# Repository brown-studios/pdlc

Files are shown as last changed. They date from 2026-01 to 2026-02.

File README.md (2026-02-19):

# PDLC driver

Drives [polymer dispersed liquid crystal (PDLC) film](https://en.wikipedia.org/wiki/Smart_glass#Polymer-dispersed_liquid-crystal_devices) from a 12 V DC nominal power supply.

PDLC film is opaque when turned off and becomes clear when turned on.  For example, you can apply it to a window to replace a privacy curtain or to create a diffuse surface for a projection screen on demand.

## Features

Here are some of the features of this PDLC driver board:

- Runs on a 12 V DC battery or power supply at a maximum of 16 V DC
- Drives approximately 4 square meters of PDLC film depending on its electrical characteristics with 15 W of power at 60 V AC peak-to-peak nominal
- Shuts off automatically to protect the battery when the supply voltage falls below 10.6 V DC and resumes operation at 11.5 V
- Includes several forms of circuit protection for the supply and the film
- Detach the terminal blocks from the device for easier wiring
- Optional external I/O functions
  - Connect the mode input to an external momentary push button or a normally open switch to control the state of the film from a convenient location
  - Connect the output enable control signal to a switch to control whether the PDLC film is operable (e.g. can be wired to a door sensor to prevent activation of the film when the door is opened)
  - Connect the auxiliary load output to control another device in tandem with the PDLC film, supports low-side switching of a 200 mA load at up to 20 V maximum (e.g. can be wired to an external indicator)
  - Connect an external I2C controller to control the driver programmatically
  - Connect your own accessories to the expansion port

Please refer to the [design and errata](./hardware/v2/design-and-errata.md) for technical details and schematics.

## Usage

If you have not yet [installed](#installation) and [setup](#setup) the device, do that first then proceed with usage.

How you use the PDLC driver depends on how you have configured it and integrated it with other systems.

By default, the PDLC film toggles on and off when you press the `MODE` button on the device.  When the film is on, it will turn clear, and when it is off, it will become diffuse and provide privacy.  The transition usually happens in less than a second but the film may take longer to change depending on your configuration settings or when the window is very cold.

You can connect an external push button or switch to change the state of the film from a more convenient location. If you have one, use that actuator instead of the `MODE` button.

As a safety feature, the film will not turn on unless the output enable control signal is active, so you may also need to perform another action to enable the film (such as closing the door if you have connected the output enable to a door switch).

You can connect an auxiliary load to the PDLC driver and configure it such that it turns on or off based on the state of the PDLC film automatically. So turning on or off the PDLC film can have additional effects depending on how you have wired things up.

Also, you can programmatically control the PDLC driver using I2C and adjust many internal settings and use advanced functionality such as dimming.  You'll need to write code for this or use an integration that someone else has made.

The `POWER` indicator illuminates for 10 seconds after you supply power to the device then turns off.

The `STATUS` indicator color indicates the status of the PDLC driver during normal operation.  The indicator may blink a certain number of times, pause, then repeat to encode information about a problem.  This table explains the significance of the patterns.

| Status color | Pattern | Meaning |
| --- | --- | --- |
| GREEN | steady | The PDLC driver is providing power to the PDLC film. |
| YELLOW | steady | The PDLC driver is turning on and verifying its operation. |
| AMBER | 1 blink | The PDLC driver was commanded to turn the film on but the output enable control signal is inactive so the driver is not providing power to the PDLC film. |
| RED | 1 blinks | HV_TIMEOUT: Boost converter did not report power good within the expected time after being enabled. |
| RED | 2 blinks | HV_FAULT: Boost converter reported power good then subsequently reported not power good. |
| RED | 3 blinks | OUTPUT_TIMEOUT: Buck converter did not report power good within the expected time after being enabled. |
| RED | 4 blinks | OUTPUT_FAULT: Buck converter reported power good then subsequently reported not power good. |
| RED | 5 blinks | DRIVER: An error occurred in the driver. |

Refer to the [setup](#setup) guide for information about how this indicator is used while configuring settings.

## Troubleshooting

When the PDLC film doesn't turn on when you think it should...

- Try turning the film off then on again and look at the `STATUS` indicator for clues.  Perhaps the output is not enabled.
- Disconnect and reconnect power to the device.  The `POWER` indicator should illuminate briefly once power is connected.
- Ensure that your power supply or battery is supplying at least 11.5 V to the device.
- Check that the settings are compatible with your installation.
- If under programmatic control, disconnect the external I2C controller, factory reset the settings, and try again using the built-in buttons to confirm basic operation.
- Check all wiring connections, fuses, and external control inputs.

When the PDLC film doesn't turn off when you think it should...

- Check that the settings are compatible with your installation.
- Check all wiring connections, fuses, and external control inputs.

## Setup

If you have not yet [installed](#installation) the device, do that first then proceed with setup.

Start by locating the `MODE` button, `SET` button, and `STATUS` indicator on the PDLC driver [as shown during installation](#installation).  Here's how to navigate the setting menus.

1. If you have connected an external switch to the `CONTROL CTRL_MODE_IN` terminal, then turn the switch off before changing settings to prevent interference with the `MODE` push button of the PDLC driver.
2. Press the `SET` button to turn off the PDLC film and enter the first setting menu.
3. Look at the `STATUS` indicator.
  - The color of the status indicator tells you which setting menu is active.
  - The indicator will blink a certain number of times, pause, then repeat.  The number of blinks tells you which option of the setting menu is selected.
4. Press the `MODE` button to advance to the next option.  The indicator will begin blinking a different number of times corresponding to the newly selected option.
5. Press the `SET` button to advance to the next setting menu and the color of the `STATUS` indicator will change.  Repeat from step 3 to continue changing settings.
6. Once you have configured the last option, the `STATUS` indicator will turn off and return to normal function.  Similarly, if you wait 30 seconds without interacting with the setting menu the device will exit the setting menu automatically.

> ![IMPORTANT]
> To reset the device to factory default settings, press and hold the `SET` button for 10 seconds until the indicator cycles through a rainbow pattern to confirm.

| Menu color | Option blinks  | Behavior |
| --- | --- | --- |
| BLUE | 1 (default) | The PDLC film toggles on and off each time `MODE` is pressed. Use this option when you connect a momentary push button to the `CONTROL CTRL_MODE_IN` terminal. |
| BLUE | 2 | The PDLC film turns on while `MODE` is pressed and turns off while `MODE` is released. Use this option when you connect a normally open switch to the `CONTROL CTRL_MODE_IN` terminal. |
| BLUE | 3 | The PDLC film state is always on whenever the output enable control signal is active. Use this option when you are controlling the PDLC driver programmatically and do not want the `MODE` button to interfere. |
| BLUE | 4 | The PDLC film state is always off. Use this option when you are controlling the PDLC driver programmatically and do not want the `MODE` button to interfere. |
| MAGENTA | 1 (default) | The PDLC film transitions from opaque to clear as quickly as possible. |
| MAGENTA | 2 | The PDLC film transitions from opaque to clear gradually over a duration of about 0.5 seconds. |
| MAGENTA | 3 | The PDLC film transitions from opaque to clear gradually over a duration of about 1 second. |
| MAGENTA | 4 | The PDLC film transitions from opaque to clear gradually over a duration of about 2 seconds. |
| CYAN | 1 (default) | The auxiliary load output turns on when the PDLC film is on and turns off otherwise (same state). |
| CYAN | 2 | The auxiliary load output turns off when the PDLC film is on and turns on otherwise (opposite state). |
| CYAN | 3 | The auxiliary load output is always on. |
| CYAN | 4 | The auxiliary load output is always off. |

## Installation

To begin installing and using your PDLC driver, locate these parts of your device:

| Part | Function |
| --- | --- |
| `POWER` terminal block | Connect the power supply and the PDLC film as described in the [wiring guide](#wiring). |
| `CONTROL` terminal block | Connect the control inputs and outputs as described in the [wiring guide](#wiring). |
| `POWER` indicator | Indicates that the device has power.  Turns off automatically after a few seconds of inactivity. |
| `STATUS` indicator | Indicates the status of the device and provides visual feedback while you configure settings. |
| `MODE` button | By default, toggles the PDLC panel on/off.  Can be configured to behave in other ways. |
| `SET` button | Configures device settings. |
| `EN` solder jumper | Solder closed to force the output enable control signal to be always active. |
| `EXT I2C` connector | Allows an external device to control the PDLC driver programmatically using a [QWIIC-compatible](https://www.sparkfun.com/qwiic) I2C interface with galvanic isolation. Additional I2C devices can also be connected in a daisy-chain. |
| `EXPANSION` header | Connect your own accessories to this port to take advantage of otherwise unused microcontroller pins. |

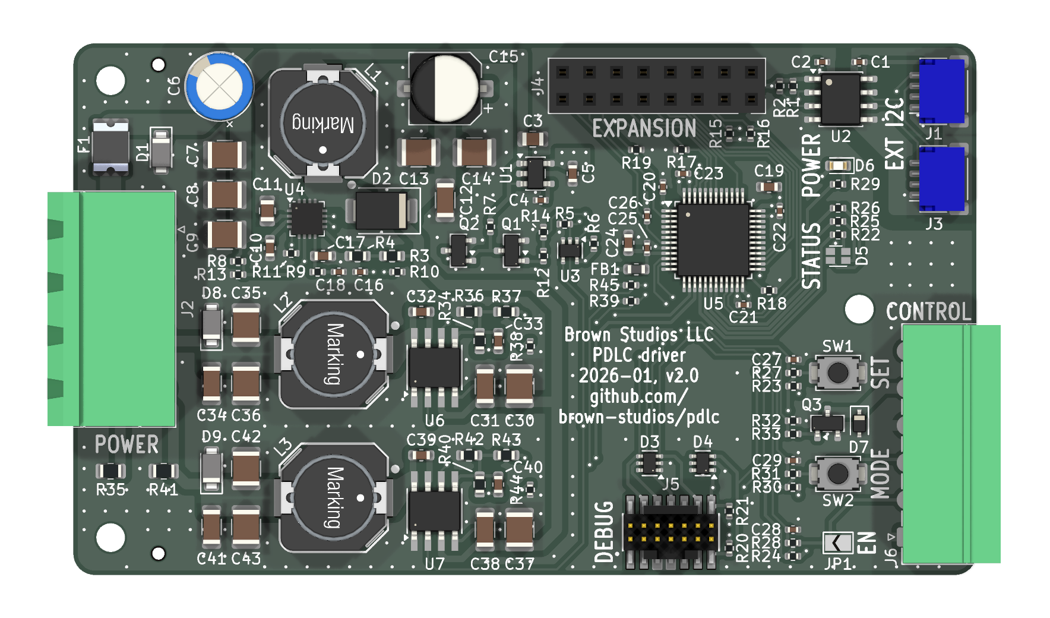
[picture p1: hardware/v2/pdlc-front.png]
PCB front


### Identify the terminals

Remove both terminal blocks from the device by grasping the sides of a block and gently pulling the block out from its socket.  Do not tug on any wires that you may have already connected to the terminal blocks because pulling on the wires could damage them.

Identify the terminals of each terminal block.  You may use the silkscreen legend on the back side of the PCB as a guide, taking care to note the orientation of the connector when it is plugged in.  The following sections will describe these connections in more detail.

We recommend crimping [electric wire ferrules](https://en.wikipedia.org/wiki/Electric_wire_ferrule) onto the wires before screwing them into place to make your connections more secure.  Only moderate screw tension is required.

| Block | Terminal | Name | Function |
| --- | --- | --- | --- |
| POWER | 1 | GND | Power supply input with negative polarity. |
| POWER | 2 | 12V_IN | Power supply input with positive polarity. |
| POWER | 3 | PDLC_OUT_A | PDLC panel AC output A. |
| POWER | 4 | PDLC_OUT_B | PDLC panel AC output B. |
| CONTROL  | 1 | GND | Connected to `POWER GND`. |
| CONTROL  | 2 | CTRL_EN_IN | Output enable switch input.  Active when connected to `GND`. |
| CONTROL  | 3 | CTRL_MODE_IN | Mode switch input.  Active when connected to `GND`. |
| CONTROL  | 4 | GND | Connected to `POWER GND`. |
| CONTROL  | 5 | LOAD_OUT | Auxiliary load output. |
| CONTROL  | 6 | 12V_OUT | Connected to the 12V rail downstream of the internal fuse circuit protection.  DO NOT CONNECT TO POWER SUPPLY. |

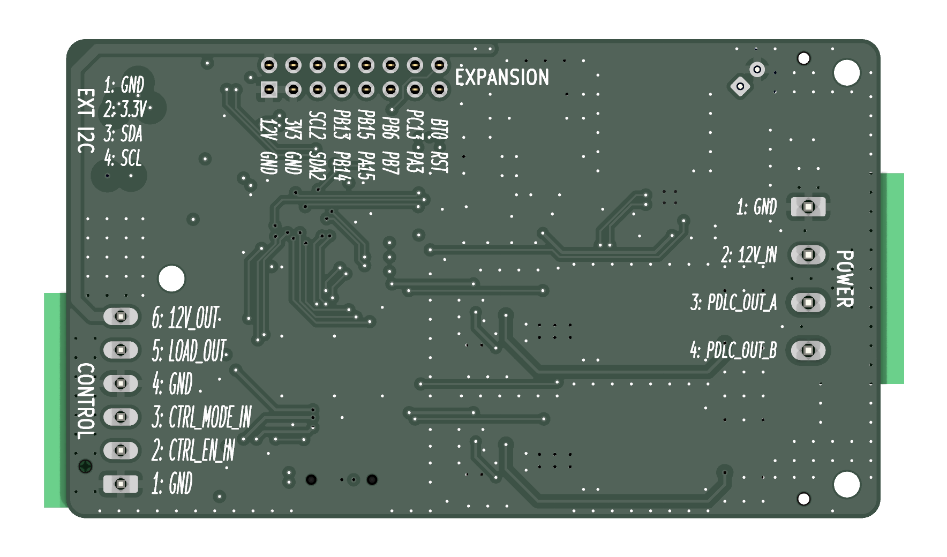
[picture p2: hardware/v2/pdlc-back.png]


### Connect the power supply (required)

You must connect the driver to a suitable 12 V DC nominal power supply.  It must be capable of supplying at least 2 amps of current and have suitable overcurrent protection such as a fuse or circuit breaker.

Use 20 AWG (0.5 mm^2) wire or larger to make the connections.

Connect the `POWER GND` terminal to the negative (ground) side of your power supply.

Connect the `POWER 12V_IN` terminal to a 3 A fuse or circuit breaker attached to the positive side of your power supply.

### Connect the PDLC film (required)

Use 22 AWG (0.3 mm^2) wire or larger to make the connections, preferably double-insulated.

Connect the `POWER PDLC_OUT_A` and `POWER PDLC_OUT_B` terminals to the PDLC film.  Either terminal can be connected to the PDLC film in either orientation because the film uses AC and there is no distinct polarity.

> ![WARNING]
> The PDLC power wires carry high voltage similar to domestic electrical wiring systems.  They can deliver a small electric shock that could be harmful to people so please ensure that these wires are adequately insulated and without exposed connections that could accidentally be touched!
>
> If the connection passes through a contact surface that might intermittently be exposed to people or to the environment (such as through a sliding door contact plate) install a safety device to deactivate the output enable control signal (such as a door switch) when those contacts may be exposed to reduce the risk of harm.

### Connect the output enable control signal (required)

The PDLC driver only provides power to the PDLC film when the output enable control signal is connected to ground.  This mechanism can be used to implement safety features to automatically disable the film when it is not safe to operate (such as when the contacts may be exposed as described in the previous section) or to remotely enable or disable the film using other devices.

> ![IMPORTANT]
> By default, the output enable control signal is not connected to anything (it is inactive) and the driver will not operate the PDLC film.  So for the PDLC film to operate, you must make a connection to activate the output enable control signal.

Here are three ways to do activate the output enable control signal:

- Connect a switch between the `CONTROL CTRL_EN_IN` and `CONTROL GND` terminals that is closed whenever it is safe to operate the PDLC film and open otherwise.  Alternatively, you may use a relay, transistor, or an optocoupler to drive the signal low (connect it to ground).
- Connect a short piece of wire with bare ends between the `CONTROL CTRL_EN_IN` and `CONTROL GND` terminals to ensure that the signal is always active when there is no reason to disable the film.
- Solder the `EN` jumper closed to bypass the `CONTROL` terminal block and ensure that the signal is always active when there is no reason to disable the film.

### Connect an external mode actuator (optional)

Optionally, you can connect an external actuator to control the mode of the PDLC driver from a more convenient location such as when you install the PDLC driver inside of a cabinet.

Choose one of following actuators and make note of its corresponding `MODE` behavior.

| Actuator type | Behavior | Description |
| --- | --- | --- |
| SPST momentary push button | Toggle | Toggle the film on or off each time the button is pressed. |
| SPST normally open switch  | On / Off | Turn the film on when the switch is closed and off when the switch is open. |

Use 24 AWG (0.2 mm^2) wire or larger to make the connections.

Connect the actuator to the `CONTROL CTRL_MODE_IN` and `CONTROL GND` terminals such that the circuit is closed when the button is pressed or the switch is in the on position.

In place of a button or switch, you may use different actuators that perform a similar electric function, such as a relay, transistor, or optocoupler to drive the signal low (connect it to ground).  And you may also connect multiple push button actuators in parallel to toggle the mode from several locations.

Later during [setup](#setup) you must set the mode button behavior for the type of actuator that you selected.

### Connect an auxiliary load (optional)

Optionally, you can connect an auxiliary load that will receive power when the PDLC film is either on or off according to the settings.  You can use this output to power an external indicator, relay, optocoupler, or other small load that can switch on and off based on the PDLC film state.

Use 24 AWG (0.2 mm^2) wire or larger to make the connections.

Connect the `CONTROL LOAD_OUT` terminal to the negative terminal of the load.

Connect the load's positive terminal to the load's power supply, preferably with adequate current limiting or a small fuse to stay within the rating of the load output.  The load's power supply must share a common ground with `CONTROL GND`.

> ![IMPORTANT]
> The auxiliary output is a low-side solid state switch (MOSFET).  When active, the `CONTROL LOAD_OUT` terminal behaves as if it has been shorted to `CONTROL GND` which completes the circuit to power the load.  The load output is rated for drive 200 mA at up to 20 V maximum.  Please pay attention to the current requirements of the load to avoid exceeding the rating and damaging your devices.

### Connect an external I2C controller (optional)

Optionally, you can connect the PDLC driver to an external I2C controller.

Connect the controller to either port labeled `EXT I2C` using a standard 4-pin QWIIC bus JST SH connector.  You may also connect additional devices downstream using the other port to form a daisy-chain.

The circuit board has an [ISO1640](https://www.ti.com/lit/ds/symlink/iso1640.pdf) to galvanically isolate the PDLC driver from the I2C port.  Here's what that means:

- The devices can be powered on and off independently (hot-plugging).
- The devices do not need to be connected to the same ground so they can be powered from different supplies and they will not form ground loops when connected.  The isolation barrier is rated for at least 450 Vrms which is suitable for many automotive applications where devices are nominally connected to the same chassis ground but there may be a small voltage difference between nodes.
- The PDLC driver's `EXT I2C` port is protected from ESD (electrostatic discharges).

(TODO: Link to the I2C target protocol)

### Plug the terminal blocks into the device (required)

Now that you have made all of the wiring connections, turn off or disconnect the power supply, gently plug the terminal block in until they are fully seated, then turn on or reconnect the power supply.

Congratulations!  Now you're ready to setup the device configuration (if you need to change the defaults).

## Electrical information

### Recommended operational parameters and circuit protection

Supply:

- Voltage: 12 V DC nominal and absolute maximum range from 10 to 16 V DC
- Wiring: minimum 20 AWG (0.5 mm²)
- Circuit protection
  - Internal: built-in 2 A polyfuse, transient voltage suppressor, reverse polarity protection, and under voltage lock-out below 10.6 V
  - External: add a 3 A fuse or circuit breaker to protect the wiring to the device

Load:

- Voltage: 60 V AC nominal at 100 Hz
- Current: 300 mA maximum continous load
- Power output: 15 W maximum continuous load
- Circuit protection
  - Internal: built-in overload, over voltage, and over temperature protection
  - External: ensure wires are adequately insulated and not exposed to touch

In case of an overload such as exceeding the maximum output current or a short circuit, the power supply will hiccup until the overload condition is removed.

Please test your set up carefully if you choose to operate the PDLC driver beyond these recommendations.

### PDLC film electrical characteristics

Here is some general information about the electrical characteristics of PDLC films for which this driver was design.  If your PDLC film has significantly different electrical characteristics, please follow the tuning instructions or contact the author for advice on using this driver with your film.

The film's capacitance is proportional to its surface area, around 10 uF per square meter.  It becomes clear when charged and opaque when discharged.

The film's resistance is inversely proportional to its surface area, generally in the tens to hundreds of kiloohms.  It self-discharges rapidly and becomes opaque when power is removed.

The film's clarity increases with voltage.  It is opaque at 0 V, begins to clear around 20 to 30 V, is nearly transparent around 50 V, and becomes slightly clearer with increasing voltage.

The film must be driven with AC to produce an alternating electric field to orient the liquid crystals and it may be damaged when driven in one polarity for too long.  At very low frequencies, the film acts as a shutter.  As the frequency rises to a few hertz, the film will appear to pulse between opaque and clear states.  At higher frequencies, the film appears clear.  Mains AC frequencies (50 / 60 Hz) seem adequate.

### PDLC film data

Here's some information about PDLC films that the driver has been tested with.  

- FilmBase PDLC self-adhesive grey film
  - Operating voltage: 60 V AC (manufacturer recommendation)
  - Frequency: 50/60 Hz (manufacturer recommendation)
  - Power: < 5W / m^2 (manufacturer claim)
  - Capacitance: ~12 uF / m^2 (measured)

## How to build the firmware

The firmware is based on Zephyr RTOS v4.3 and compiled with `west`.

1. Install the Zephyr RTOS SDK tools.  You can either follow the [Zephyr Getting Started Guide](https://docs.zephyrproject.org/latest/develop/getting_started/index.html) or install an extension for your IDE, such as [Zephyr IDE](https://zephyr-ide.mylonics.com/) or [Workbench for Zephyr](https://z-workbench.com/), that can install the tools for you.

2. Install the [xPack OpenOCD](https://xpack-dev-tools.github.io/openocd-xpack/docs/install/) package for your OS and add it to your system `PATH`.  This step is needed because the version of OpenOCD that is distributed with Zephyr is too old.  We need OpenOCD v0.12.0-7 at minimum.

3. Get the code and its dependencies.  This is a little more complicated than simply cloning this git repository because the Zephyr `west` multi-tool assumes that all of the code resides within a top directory called a workspace.  You will need to create an empty directory to be the workspace first.  Here's how to do it from the command-line and the same thing can be done with IDE extensions.

```sh
$ mkdir pdlc-workspace
$ cd pdlc-workspace
$ west init -m https://github.com/brown-studios/pdlc
$ west update
```

4. Build and the firmware (either release or debug).

```sh
$ cd pdlc/firmware/app
$ west build -p -d build/release
$ west build -p -d build/debug -- -DFEATURE_LOG=y -DFEATURE_DEBUG=y
```

5. Connect an ST-Link v3 programmer to the `DEBUG` port with an `STDC14` cable.  Flash the firmware.

```sh
$ cd pdlc/firmware/app
$ west flash
```

## Design history

v2.0: Second prototype.  Uses a microcontroller to generate commutation waveforms in software and more careful circuitry to limit the output current.  Should work with larger panels and be safer to operate.  Can be controlled with two switch inputs and interface with a host device as an I2C target.

v1.0: Initial prototype.  Uses a 555 timer and inverter to generate commutation waveforms.  Works fine for small PDLC samples.  Can't drive larger panels without modification because it does not wait for the power-good signal to be asserted before energizing the panel and it does not limit the current so it hiccups.  During testing, the board was modified to replace the timer with a microcontroller to generate PWM signals in open loop control which helped it drive larger panels but it still could not achieve the expected output power.

## Notice

The PDLC driver software, documentation, design, and all copyright protected artifacts are released under the terms of the [MIT license](LICENSE).

The PDLC driver hardware is released under the terms of the [CERN-OHL-W license](hardware/LICENSE).

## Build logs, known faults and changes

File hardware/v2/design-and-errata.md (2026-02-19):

# PDLC driver v2

**Status: v2.0 fabricated and tested, not recommended for production, see errata**

**Status: v2.1 update pending with optimized part selection**

## Design synopsis

The driver has the following major components:

- [LM5158](https://www.ti.com/lit/ds/symlink/lm5158.pdf) boost converter produces high voltage DC at 300 mA
- Two [LMR38010](https://www.ti.com/lit/ds/symlink/lmr38010.pdf) buck converters produce variable voltages between 3 V and 63 V for each AC leg
- [STM32L151C8T6](https://www.st.com/resource/en/datasheet/stm32l151c8-a.pdf) microcontroller with 64 KB flash and 32 KB RAM generates waveforms and monitors control signals
- [ISO1640](https://www.ti.com/lit/ds/symlink/iso1640.pdf) galvanically isolates the external I2C bus when connected to other devices
- [LP2985-33](http://www.ti.com/lit/ds/symlink/lp2985.pdf) LDO powers the logic circuits at 3.3 V
- Circuit protection elements
  - Supply: 2 A polyfuse, TVS, UVLO battery saver
  - PDLC: undervoltage, overcurrent hiccup, short-circuit, bleed resistor, TVS, power good sequencing
  - Switch inputs: ESD diodes
  - External I2C bus: galvanic isolation, hot plug

## Illustrations

[Schematics PDF](pdlc.pdf)

### PCB front
PCB front

### PCB back
PCB back

## Fabrication

Use the `JLCPCB fabrication toolkit` plug-in to generate files for JLCPCB.

Fabrication parameters:

- Material: 4 layers, FR4 TG155, ENIG, 1 oz outer copper, 0.5 oz inner copper
- Via covering: plugged
- Min via hole size: 0.3 mm (default)
- Board outline tolerance: 0.2 mm (default)
- Assembly side: top
- Tooling holes: by customer
- Parts selection: by customer
- Solder paste: high temp (default)

Because the terminal block plugs must be bought separately, it may be better to buy the receptacles too and solder them manually after manufacture.  Alternatively, you could use one of the receptacle clones from JLCPCB's inventory and hope they are sufficiently compatible with the separately purchased plugs.

## Details

### High voltage boost converter ([LM5158](https://www.ti.com/lit/ds/symlink/lm5158.pdf))

The high voltage boost converter raises the voltage from the supply to the intermediate high voltage DC needed to drive the PDLC panels.

This circuit was initially modeled in TI WebBench with the following parameters:

- Vin_min: 11 V
- Vin_max: 16 V
- Vout: 65 V
- Iout_max: 300 mA
- Ambient temperature: 30 C
- Hiccup protection: enabled
- Spread spectrum: enabled
- UVLO: not applicable (the tool can't calculate values in the necessary range, see below)
- Switching frequency: 1.6 MHz
- Soft start time: 16 ms

Resulting performance at Vin = 12 V, Iout = 0.3 A

- Total power dissipation: 0.9 W
- Efficiency: 95.6%

The design was then modified as follows:

- Selected a small format 10 mm x 10 mm shielded drum core inductor: 15 uH Wurth 7447714150 in WE-PD 1050 package.
- Selected X7R/X7S MLCC capacitors with relatively small DC bias derating at the operating voltage based on the manufacturer datasheets.
- Selected UVLO resistors with more common values.  Refer to [calc.py](./calc.py) for the calculations.  Added transistors to pull UVLO low when not enabled.
- Selected feedback resistors with more common values, Rfb_t = 330 K, Rfb_b = 5.1K.  So Vout = 1 V * (Rfb_t / Rfb_b + 1) = 65.7 V.
- Added bulk capacitors to the input and output.
- Optimized part selection for cost and availability at JLCPCB.  Unfortunately, the 22 uH inductor used in the previous design (with a lower switching frequency) was out of stock so 15 uH was used (at a higher switching frequency) instead.

### Variable voltage buck converters ([LMR38010](https://www.ti.com/lit/ds/symlink/lmr38010.pdf))

The two variable voltage buck converters modulate the high voltage DC to produce AC with waveforms driven by a DAC.  This design is modeled on the SDAA033 document reference (see below) with some changes to the underlying assumptions.

- Unlike SDAA033, this design does not assume that the waveform is sinusoidal as some sources suggest that an AC square wave may yield better clarity in the PDLC film and it would be nice to experiment with non-sinusoidal waveforms while still ramping the voltage to limit capacitive in-rush current: in other words, increase the slew rate for rise-and-fall, and inject a hold time in between.  It may therefore be inaccurate to estimate power dissipation at the Vrms operating point.  Once the PDLC film charges to the applied voltage, its current draw should be determined by its parasitic resistance (assumed to be somewhat large) and the buck converter should enter the PFM mode where it skips pulses due to low current demand from the load.  The total energy transferred should be similar regardless of the shape of the waveform although a faster slew rate implies that high voltage boost converter must supply more current and will dissipate more power during the ramp.
- The selected LMR38010 switch Rds_on is about 3 times larger than the LM65635 considered in SDAA0033 so its switching losses are greater.  Unfortunately those LM656xx high performance parts were not readily available at JLCPCB at the time of this design and the few that were cost 10x as much.  The LMR38010 also has a higher input voltage of 80 V instead of 65 V which increases the margin for this application.
- LMR38010 and LMR38020 are pin-equivalent and only differ by their overcurrent thresholds.  We choose LRM38010 which has a 1 A rating because the high-side overcurrent protection limit of 1.6 A allows the use of smaller inductors with a lower DC current rating.  Thus the selected inductor's Isat must be greater than 1.6 A to prevent the inductor from entering saturation.  Curiously, LMR38010 costs a little more.  The LMR38020 data sheet is a bit richer and provides additional useful formulas and tables that should apply to both parts.
- The LMR38010 data sheet recommends setting Iout_max to the full device current rating (1 A) during design when the actual load current (300 mA) is much smaller.  Note that choosing a larger Iout_max results in a design with smaller inductors.
- The buck converters may be damaged if the switching node drops below 0 V so we choose Vout_low = 3 V and Vout_high = 63 V to allow a safety margin for generating a 60Vp-p waveform between a pair of buck converters supplied with Vin = 65.7.
- To avoid oversizing the device, we follow the guidance of SDAA033 and set the Vout design operating point to the RMS voltage.  So Vout = (Vout_high - Vout_low) / sqrt(2) + Vout_low = 45.4 V.
- The selected buck converter must operate in FPWM mode because PFM mode cannot sink current from the output.

This circuit was initially modeled in TI WebBench with the following parameters:

- Vin_min: 65.7 V
- Vin_max: 65.7 V
- Vout: 45.4 V
- Iout_max: 1 A
- Ambient temperature: 30 C
- Switching frequency: 500 kHz
- UVLO: not applicable
- Output cap type: ceramic
- Power good resistor: open

The design was then modified as follows:

- Selected a small format 10 mm x 10 mm shielded drum core inductor: 68 uH Wurth 7447714680 in WE-PD 1050 package.
- Selected X7R/X7S MLCC capacitors with relatively small DC bias derating at the operating voltage based on the manufacturer datasheets.
- Selected Rt for the switching frequency.  Noticed that TI WebBench sometimes suggests a value that differs from the formula and tables in the data sheets so made sure to verify it.
- Selected feedback resistors based on the method described in [SLYT777](https://www.ti.com/lit/an/slyt777/slyt777.pdf).  The STM32L151 DAC electrical specifications specify that Vdac is linear in the range of 0.2 V to Vdda - 0.2 V where Vdda = 3.3 V for this application so we choose a margin of at least 0.3 V to stay safely within the linear range.  The buck converter internal feedback voltage reference is Vfb_ref = 1 V and it recommends Rfb_t >= 100 K.  Refer to [calc.py](./calc.py) for the calculations.

Operating points:

| label | Vadj | Vout | DAC code |
| ----- | --- | --- | --- |
| 0 | 0.00 V |  69.81 V | 0 |
| min | 0.20 V |  65.41 V | 248 |
| low | 0.31 V |  63.01 V | 383 |
| mid | 1.67 V |  33.00 V | 2076 |
| rms | 1.11 V |  45.43 V | 1375 |
| high  | 3.04 V | 2.99 V | 3769 |
| max | 3.10 V | 1.61 V | 3847 |
| Vdda  | 3.30 V |  -2.79 V | 4095 |

## Pin function map

### Debug

- NRST: RESET
- BOOT0: BOOT0, boot mode selection, external pull-down
- BOOT1 on PB2: BOOT1, boot mode selection, external pull-down
- SWDIO on PA13: SWDIO, serial wire data
- SWCLK on PA14: SWCLK, serial wire clock
- SWO/JTDO on PB3: SWO, serial wire trace output

### Console

- USART1_TX on PA9: CONSOLE_TX, serial TX
- USART1_RX on PA10: CONSOLE_RX, serial RX

### External I2C bus (receives messages as target)

- I2C1_SCL on PB8: EXT_I2C_SCL, serial clock
- I2C1_SDA on PB9: EXT_I2C_SDA, serial data 

### Internal I2C bus (sends messages as controller)

- I2C2_SCL on PB10: INT_I2C_SCL, serial clock
- I2C2_SDA on PB11: INT_I2C_SDA, serial data 

### PDLC driver

- GPIO on PB4: HV_EN, active high
- GPIO on PB5: HV_PG, active high
- DAC_OUT1 on PA4: PDLC_ADJ_A, AC waveform generator
- DAC_OUT2 on PA5: PDLC_ADJ_B, AC waveform generator
- GPIO on PA8: PDLC_EN, active high
- GPIO on PC14: PDLC_PG_A, active high
- GPIO on PC15: PDLC_PG_B, active high

TIM6 and TIM7 reserved for internal use to initiate DAC DMA requests.

### Control I/O

- GPIO on PA0 (EXTI0, WKUP1): CTRL_MODE, mode button, active low, wake-up from standby occurs on low-to-high transition (after the switch is released)
- GPIO on PA1 (EXTI1): CTRL_SET, setting button, active low
- GPIO on PA2 (EXTI2): CTRL_EN, output enable switch, active low
- TIM10_CH1 on PB12: LOAD_EN, load enable signal, active low

When LOAD_EN is high, then LOAD_OUT is driven low, rated for 200 mA at 20 V.

### Indicator LEDs

- TIM3_CH1 on PA6: LED_STATUS_R, PWM output, active low
- TIM3_CH2 on PA7: LED_STATUS_G, PWM output, active low
- TIM3_CH3 on PB0: LED_STATUS_B, PWM output, active low
- TIM3_CH4 on PB1: LED_POWER, PWM output, active low

### Unused pins available for expansion

- PA3 (ADC_IN3, COMP1_INP, TIM2_CH4, TIM9_CH2)
- PA15 (---)
- PB6 (TIM4_CH1)
- PB7 (TIM4_CH2)
- PB13 (ADC_IN19, COMP1_INP, TIM9_CH1)
- PB14 (ADC_IN20, COMP1_INP, TIM9_CH2)
- PB15 (ADC_IN21, COMP1_INP, TIM11_CH1)
- PC13 (WKUP2): wake-up from standby occurs on low-to-high transition when enabled in PWR_CSR register, external pull-down

### Unused pins reserved

- PA11 (USB_DM): USB data -
- PA12 (USB_DP): USB data +
- PH0 (OSC_IN): HSE oscillator (requires 24 MHz clock for USB)
- PH1 (OSC_OUT): HSE oscillator

### [System bootloader](https://www.st.com/resource/en/application_note/an2606-stm32-microcontroller-system-memory-boot-mode-stmicroelectronics.pdf) configured pins

- Can access system bootloader via the console UART or USB
- Pull-up inputs: PA10
- Pull-up outputs: PA9
- USB: PA11, PA12

## References

### Documents

#### STM32

[AN3216 Getting started with STM32L1xxx hardware development](https://www.st.com/resource/en/application_note/an3216-getting-started-with-stm32l1xxx-hardware-development-stmicroelectronics.pdf)

[STM32L151C8-A datasheet](https://www.st.com/resource/en/datasheet/stm32l151c8-a.pdf)

[STM32L1xxxx reference manual](https://www.st.com/resource/en/reference_manual/rm0038-stm32l100xx-stm32l151xx-stm32l152xx-and-stm32l162xx-advanced-armbased-32bit-mcus-stmicroelectronics.pdf)

#### [DC to AC Conversion with DC to DC Buck Converters for PDLC Displays (SDAA033)](https://www.ti.com/lit/an/sdaa033/sdaa033.pdf)

Using two buck converters is roughly equivalent to driving an H-bridge through an LC filter (particularly when using synchronous rectification) and uses fewer components.  The buck converter tightly monitors the feedback loop to ensure a stable output voltage under varying load conditions and handle faults which frees the microcontroller to do other work.  This is the model for the design implemented here.

#### [Smart Glass PDLC Film Driver (AN6205)](https://ww1.microchip.com/downloads/aemDocuments/documents/APID/ApplicationNotes/ApplicationNotes/Smart-Glass-PDLC-Driver-DS00006205.pdf)

Describes a more traditional PDLC driver based on an H-bridge and LC filter.

#### [An Engineer's Guide to Current Sensing (SLYY154B)](https://www.ti.com/lit/eb/slyy154b/slyy154b.pdf)

During the design process, I considered adding current sensing to protect against faults in the PDLC film when driving it with an H-bridge.  The [INA381A3](https://www.ti.com/lit/ds/symlink/ina381.pdf) in particular has a comparator output that could be attached to a timer break pin to disable the output quickly and latch until the fault is resolved or it could be used to implement cycle-by-cycle current limiting to more aggressively control the slew rate of the output.  That said, the boost converter PGOOD signal will be deasserted if the output voltage drops too low due to an overload condition or short-to-ground (which cannot be detected by low-side current sensing) so no additional protection seems necessary.

#### [Switch-mode power converter compensation made easy](https://e2e.ti.com/cfs-file/__key/communityserver-discussions-components-files/196/switchingpower_5F00_compensation.pdf)

Describes the theory of designing current control mode compensation networks.

#### [Design Feedforward Capacitor for LMR14020 (SNVA798)](https://www.ti.com/lit/an/snva798/snva798.pdf)

Describes the choice of a feed forward capacitor for an internally compensated current control mode buck converter.  The design includes a DNP pad in case it is needed.  Typical values are in the pF range.

#### [Control mode quick reference (SLYT710B)](https://www.ti.com/lit/an/slyt710b/slyt710b.pdf)

A great summary of 15 different switch mode power supply control modes and their behavior.  Useful for comparing buck converter architectures.

#### [Controlling Output Ripple and Achieving ESR Independence in Constant On-Time (COT) Regulator Designs (SNVA166A / AN-1481)](https://www.ti.com/lit/an/snva166a/snva166a.pdf)

Describes how to generate ripple in the feedback network for COT mode buck converters.

#### [Methods of output-voltage adjustment for DC/DC converters (SLYT777)](https://www.ti.com/lit/an/slyt777/slyt777.pdf)

Describes how to adjust the voltage feedback loop.  Used a DAC for this design.

### Parts

#### Buck converters

Notable qualities:

- Synchronous rectification improves efficiency and low voltage output operation.
- The control mode influences component selection.  Constant on-time (COT) and pulse frequency modulation (PFM) mode require a minimum output ripple and additional components may be needed to generate that ripple in the feedback network.  Current control mode (CC) requires requires tuning a compensation network (unless internally integrated).  Pulse frequency mode (PFM) 
- The configurable soft start input of some devices may potentially be used to adjust the internal voltage reference and thereby modulate the output voltage target instead of injecting a signal into the feedback network.
- In the v2 design, a PFM part was selected for light load efficiency but it is unable to sink current from the output so it does not suit this application, so v2.1 uses an FPWM part.

A selection of parts available at at JLCPCB/LCSC (as of January 2026):

- [LM5012](https://www.ti.com/lit/ds/symlink/lm5012.pdf): 100 V, 2.5 A, non-synchronous (need diode), COT mode (need ripple), light load efficiency
  - LM5012DDAR: $1.19/1ku, SO-8-EP, 4.9 mm x 3.9 mm
- LM5013: 100 V, 2.5 A, similar to LM5012
- [LM5017](https://www.ti.com/lit/ds/symlink/lm5017.pdf): 100 V, 600 mA, synchronous, COT mode (need ripple), no soft-start but the datasheet shows how to implement it by injecting into the feedback network (helpful!), no light load optimization
  - LM5017MRX: $0.51/1ku, SOIC-8-EP, 4.9 mm x 3.9 mm
- [LM5161](https://www.ti.com/lit/ds/symlink/lm5161.pdf): 100 V, 1 A, synchronous, COT mode (internal ripple generation in DCM mode), configurable soft-start, light load efficiency (when DCM enabled), external LDO recommended to drive VCC
  - LM5161PWPR: $1.46/1ku, HTSSOP-14, 5.0 mm x 4.4 mm
- [LM5163](https://www.ti.com/lit/ds/symlink/lm5163.pdf): 100 V, 500 mA, synchronous, COT mode (need ripple), fixed soft-start, light load efficiency (pulse skipping)
  - LM5163DDAR: $0.33/1ku, SO-8-EP, 4.9 mm x 6.0 mm
- [LM5164](https://www.ti.com/lit/ds/symlink/lm5164.pdf): 100 V, 1 A, synchronous, COT mode (need ripple), fixed soft-start, light load efficiency (pulse skipping)
  - LM5164DDAR: $0.38/1ku, SO-8-EP, 4.9 mm x 6.0 mm
- [LM5166](https://www.ti.com/lit/ds/symlink/lm5166.pdf): 65 V, 500 mA, synchronous, COT or PFM mode (need ripple), PFET switch (no bootstrap capacitor needed), configurable soft-start, adjustable current limit
  - LM5166DRCR: $0.85/1ku, VSON-10, 3 mm x 3 mm
- [LM5169](https://www.ti.com/lit/ds/symlink/lm5169.pdf): 120 V, 650 mA, synchronous, COT mode (need ripple), fixed soft start
  - LM5169PDDAR: $1.66/1ku, SOP-8-EP, 4.9 mm x 6 mm
- [LM5574](https://www.ti.com/lit/ds/symlink/lm5574.pdf): 75 V, 500 mA, non-synchronous (need diode), CC mode (need compensation), configurable soft-start (tracking feature), no light load optimization
  - LM5574: $0.85/1ku, TSSOP-16, 5.0 mm x 6.4 mm
- LM5575: 75 V, 1.5 A, similar to LM5574
- [LMR38010](https://www.ti.com/lit/ds/symlink/lmr38010.pdf): 80 V, 1 A, synchronous, CC mode (internal compensation), light load efficiency (PFM mode)
  - LMR38010SDDAR: $0.59/1ku, HSOIC-8, 4.9 mm x 3.9 mm (PFM)
  - LMR38010FSDDAR: $2.00/1ku, HSOIC-8, 4.9 mm x 3.9 mm (FPWM with spread spectrum)
- [LMR38020](https://www.ti.com/lit/ds/symlink/lmr38020.pdf): 80 V, 2 A, synchronous, CC mode (internal compensation), light load efficiency (PFM mode)
  - LMR38020SDDAR: $0.40/1ku, HSOIC-8, 4.9 mm x 3.9 mm

## Test results

### Initial tests with v2.0

Measured at V_in = 12.0 V unless otherwise stated.

| Criterion | Expected | Actual | Result |
| --- | --- | --- | --- |
| LDO voltage | V_3v3 = 3.3 V | V_3v3 = 3.003 V | PASS |
| UVLO turn on threshold | V_in >= 11.5 V | V_in >= 11.44 V | PASS |
| UVLO turn off threshold | V_in <= 10.6 V | V_out <= 10.56 V | PASS |
| Boost voltage | V_hv = 65.7 V | V_hv = 65.65 V | PASS |
| DAC A center (code 0x800) | V_adj_a = 1.65 V | V_adj_a = 1.651 V | PASS |
| DAC B center (code 0x800) | V_adj_b = 1.65 V | V_adj_b = 1.657 V | PASS |

Output voltages produced for given DAC codes with no load.

| Code        | V_out_a | V_out_b | I_in    | Remark |
|  383 (low)  | 62.50 V | 63.00 V | 0.124 A | FAIL, excess input current, theoretically expected 63.01 V |
|  400        | 62.99 V | 62.78 V | 0.072 A | FAIL, excess input current |
|  450        | 62.10 V | 62.00 V | 0.065 A | FAIL, excess input current |
|  480        | 61.57 V | 62.07 V | 0.032 A | OK |
|  500        | 61.23 V | 61.72 V | 0.032 A | OK |
|  600        | 59.46 V | 59.94 V | 0.032 A | OK |
| 1375 (rms)  | 45.87 V | 46.21 V | 0.030 A | OK, theoretically expected 45.43 V |
| 2076 (mid)  | 33.56 V | 33.79 V | 0.030 A | OK, theoretically expected 33.00 V |
| 3769 (high) |  3.72 V |  3.73 V | 0.028 A | OK, theoretically expected 2.99 V |

When a small load (6.8 K resistor) is connected between the outputs at different voltages, the output voltage rises above the setpoint expected by the feedback loop.  The [buck converter does not sink current from the output in PFM mode](https://e2e.ti.com/support/power-management-group/power-management/f/power-management-forum/1362709/lmr38010-holding-output-when-pulled-up-with-negative-current) so it cannot work in this application!

On closer examination, [SDAA033 shows the buck converter operating in PFM mode on one page and in FPWM on a different page](https://e2e.ti.com/support/power-management-group/power-management/f/power-management-forum/1615264/lmr38010-pdlc-film-driver-based-on-sdaa0033/6227563).

### Tests with v2.0 after replacing LMR38010SDDAR (PFM) with LMR38010FSDDAR (FPWM)

The FPWM buck converter sinks current as expected.  Driving the DAC with a sine wave yields a nice sinusoidal output that is capable of driving PDLC panels.  Larger panels not yet tested.

Current usage on 12 VDC supply:

- Off: 5 mA
- No load: 215 mA!
- 0.16 m^2 PDLC panel: 210 mA

The output stage is inefficient.  The buck converter dumps about 2 W into the output inductors constantly even with no load on the output.  The inductors get somewhat hot to the touch after a few minutes (temperature change not yet measured).

The PDLC panel transitions from diffuse to clear as expected but it does not achieve maximum clarity at the driven output voltage.  With the feedback configured for 3 VDC to 60 VDC peak-to-peak, the resulting output is 40 VAC RMS at 100 Hz.  The PDLC panel becomes noticeably clearer when the output voltage is raised to about 60 VAC RMS at 60 Hz (using other equipment) and becomes marginally clearer up to about 80 VAC RMS at 60 Hz.  So it would be worthwhile to increase the output voltage or experiment with changing the output waveform.

Tested short-circuit protection on the output.  Hiccups, as expected, with no damage.

Tested operation at different output frequencies with a 0.16 m^2 PDLC panel.  It seems like the outputs fall out of regulation at higher frequencies.

| Frequency | Behavior |
| --- | --- |
| 20 Hz | Visible strobing |
| 50 Hz | Slight flicker |
| 100 Hz | OK |
| 120 Hz | OK |
| 150 Hz | Buck reports not PGOOD above about 130 Hz |

## Errata

### v2.0 errata

Major issues:

- The LMR38010SDDAR buck converter operates in PFM mode and cannot sink current from the output so it does not work for this application.  Replacing it with LMR38010FSDDAR in FPWM mode works but the output stage consumes 2 W constantly even with no load on the output, raising the temperature of the inductors.

Minor nits:

- Noticed that a few vias for signal tracks near the buck converters have a smaller diameter (0.5 mm) than the board setup defaults (0.6 mm).  Still OK to manufacture.  The smaller 0.5 mm diameter is mainly used for ground plane stitching in this board as a way to tell them apart from signals.

## Updates

### Major changes since v2.0

- Replace LMR38010SDDAR with LMR38010FSDDAR for testing

### Major changes since v1

- Use an MCU to generate the commutation waveforms instead of a 555 timer.
- Add switches and indicates to toggle the mode and configure the behavior of the driver.
- Add an external I2C interface for fine-grained control of the driver by other devices.
- Use buck converters to produce the AC output with LC filtering instead of H-bridges with uncontrolled di/dt (which sort of worked for small panels and failed for larger ones).
- Add ESD protection to the external interfaces.

### Remarks

- The via stitching pattern is based on a 2 mm gap, 0.5 mm diameter, 0.3 mm hole.  Unfortunately the `kicad-action-scripts` plug-in does not respect keepout areas consistently so the vias were placed by hand.
- The schematics are plotted with dark theme `Arcana`.

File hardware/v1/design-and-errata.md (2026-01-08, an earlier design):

# PDLC driver v1.0 (OBSOLETE)

**Status: Superseded by v2.0, see [errata](#errata)**

## Features

Here are some of the features of this PDLC driver board:

- Supports approximately 4 square meters of PDLC film depending on its electrical characteristics
- Outputs ~60 V AC with up to 18 W of power from a 10 to 16 VDC power supply
- Can use a switch, relay, optocoupler, or transistor to remotely enable the driver
- Includes built-in circuit protection for the supply and load
- Power on indicator

## Design synopsis

The driver has the following major components:

- A [LM5158](https://www.ti.com/lit/ds/symlink/lm5158.pdf) boost converter produces ~60 V DC at 300 mA (actually 61 V DC) with overload, over voltage, and over temperature protection
- A [LM5108](https://www.ti.com/lit/ds/symlink/lm5108.pdf) half-bridge driver and discrete FETs produce the AC square wave output
- A [TLC555](http://www.ti.com/lit/ds/symlink/tlc555.pdf) timer and [SN74LVC1G14](https://www.ti.com/lit/ds/symlink/sn74lvc1g14.pdf) inverter generate square waves for commutation at 100 Hz
- Supply circuit protection with a 2 A polyfuse and transient voltage suppressor
- Remote enable / shutdown circuit with under voltage lock-out

[View the schematics in PDF format](pdlc.pdf)

## Circuit board

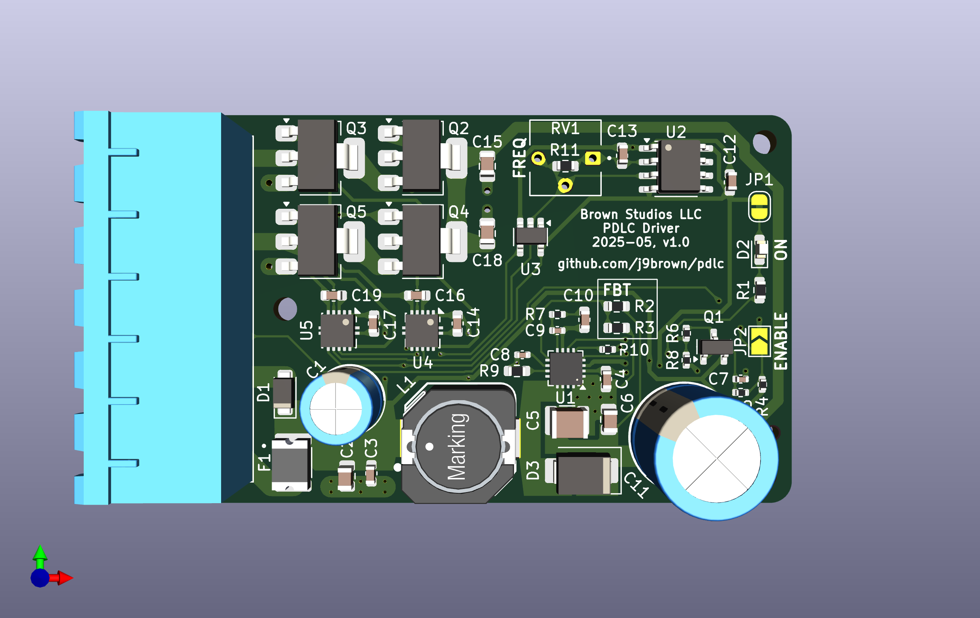
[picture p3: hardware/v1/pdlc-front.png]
Front side of circuit board


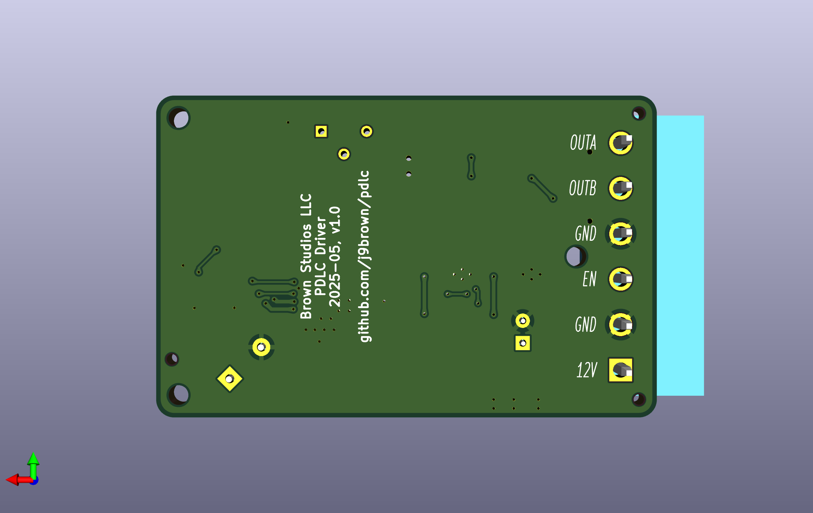
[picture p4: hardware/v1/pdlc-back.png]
Back side of circuit board


## Installation

Wire the 6-pin connector according to the labels shown on the back side of the circuit board as follows.  We recommend using crimped wire ferrules to secure stranded wires before screwing them into the terminal block.

Make sure the supply is turned off while making these connections.

Connect `12V` and one `GND` terminal to a 10 to 16 V DC supply using 20 AWG (0.5 mm^2) wire or larger.  Pay attention to the polarity: `12V` is positive and `GND` is negative.  We recommend adding a 3 A fuse or circuit breaker to protect the wiring to the device.

Connect `OUTA` and `OUTB` to the PDLC film using 22 AWG (0.3 mm^2) wire or larger.  Either terminal can be connected to the PDLC film in either orientation because the film uses AC and there is no distinct polarity.  These wires carry enough voltage to deliver a small electric shock that could be harmful to people so please ensure that the wires are adequately insulated and not exposed to touch.

Connect `EN` to one `GND` terminal via a switch circuit, via a short jumper wire, or by soldering the `ENABLE` jumper closed.  The `EN` terminal is active low so the driver turns on when `EN` is grounded and turn offs otherwise.  Use 24 AWG (0.2 mm^2) wire or larger to make the connection.  Smaller wires will work but may be too fragile for the terminals.

The switch circuit carries less than 1 mA of current at 12 V DC nominal.  You can use many kinds of switching devices to close the circuit from `EN` to `GND` such as a simple SPST rocker switch, a relay, an optocoupler, or a transistor.

If you would like to disable the power on indicator, cut the `JP1` jumper trace.

## Usage

After [installing the PDLC driver](#installation), provide power to the driver and activate the switch circuit.

If everything is working as intended, the PDLC film will become clear and the power on indicator labeled `ON` will glow red (unless it has been disabled).

If this does not happen, disconnect power then recheck your connections and the [recommended operational parameters](#recommended-operational-parameters-and-circuit-protection).

## Recommended operational parameters and circuit protection

Supply:

- Voltage: 12 V DC nominal and absolute maximum range from 10 to 16 V DC
- Wiring: minimum 20 AWG (0.5 mm²)
- Circuit protection
  - Internal: built-in 2 A polyfuse, transient voltage suppressor, reverse polarity protection, and under voltage lock-out below 9 V
  - External: add a 3 A fuse or circuit breaker to protect the wiring to the device

Load:

- Voltage: ~60 V AC square wave at 100 Hz
- Current: 300 mA maximum continous load
- Power output: 18 W maximum continuous load
- Circuit protection
  - Internal: built-in overload, over voltage, and over temperature protection
  - External: ensure wires are adequately insulated and not exposed to touch

In case of an overload such as exceeding the maximum output current or a short circuit, the power supply will hiccup until the overload condition is removed.

Please test your set up carefully if you choose to operate the PDLC driver beyond these recommendations.

### Modifying the drive parameters

**Caution: Modifying the driver's output voltage or frequency may damage the driver or the film!  We recommend testing your changes with a small sample of the material and a current limited bench power supply.**

To change the output frequency, remove the surface mount resistor within the block labeled `FREQ` (if there is one), then solder in a surface mount resistor of a different value or a potentiometer.  Ensure that the `FREQ` resistor value generates a frequency of at least a few hertz to prevent damage to the film.

To change the output voltage, remove the surface mount resistor labeled `FBT`, then solder in a surface mount resistor of a different value.

Refer to the schematics for the formulas, footprints, and default component values.

## Errata

The driver does not wait for the power-good signal to be asserted before driving the panel which results in hiccups.

The driver does not limit the current to the panel so it exceeds the available charge in the output capacitor when driving larger panels and hiccups.

During testing, the board was modified to replace the timer with a microcontroller to generate PWM signals in open loop control which helped it drive larger panels but it still could not achieve the expected output power.

The `EN` input is much too sensitive when left floating.

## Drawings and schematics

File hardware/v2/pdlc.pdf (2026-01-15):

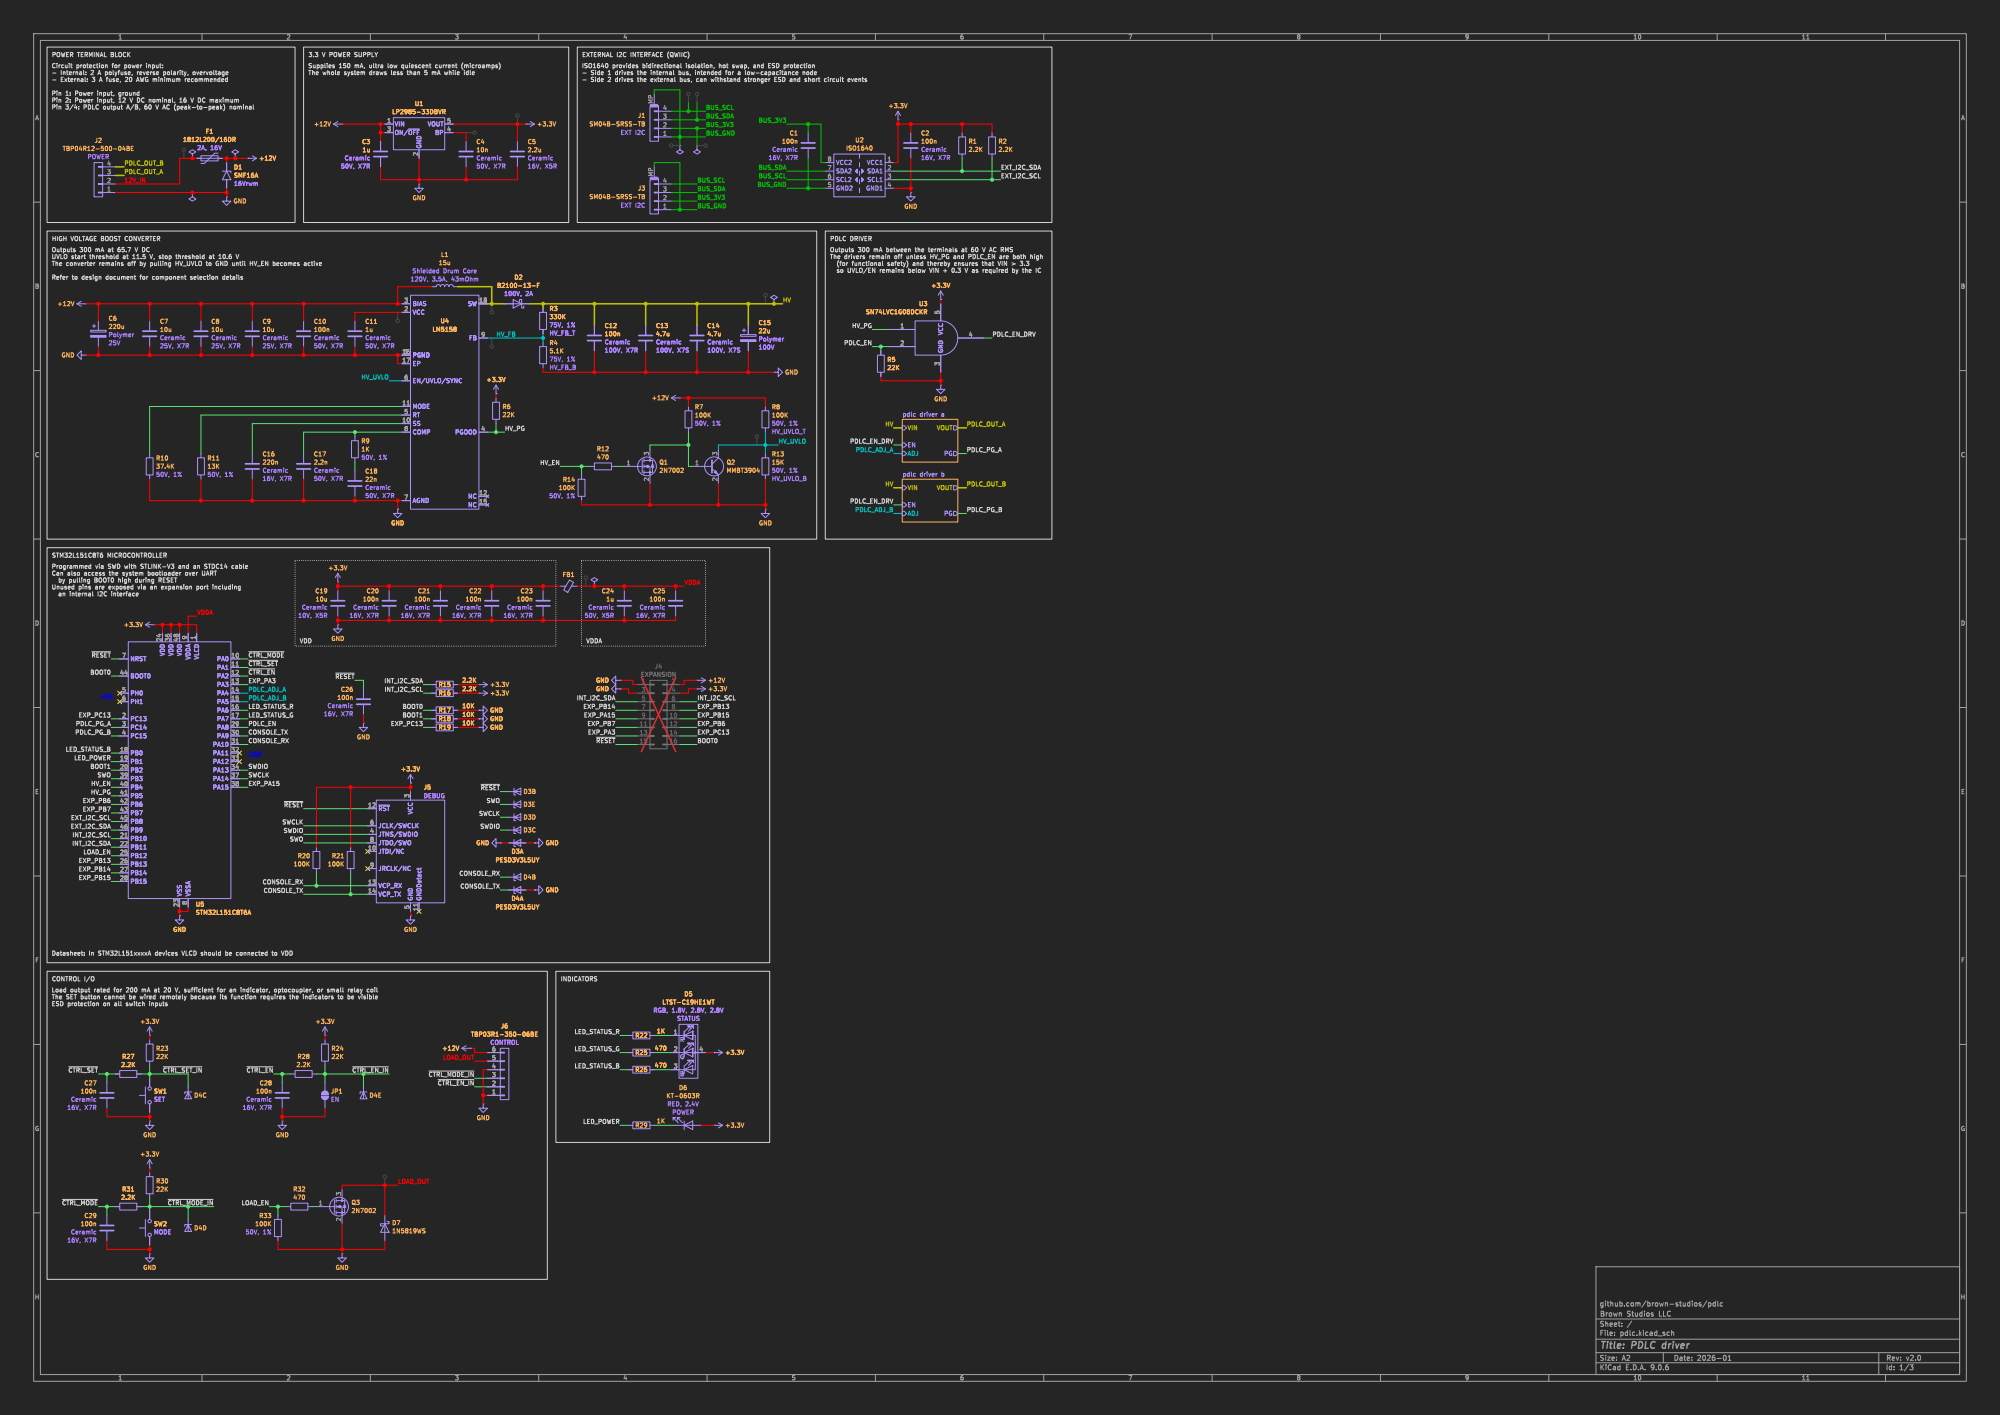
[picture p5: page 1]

HIGH VOLTAGE BOOST CONVERTER

PDLC DRIVER
22u Polymer 100V GND GND GND GND
HV_FB_T GND

The drivers remain off unless HV_PG and PDLC_EN are both high

J5DEBUG GNDDetect 11 VCC 3 GND 5 ~{RST} 12

github.com/brown-studios/pdlc

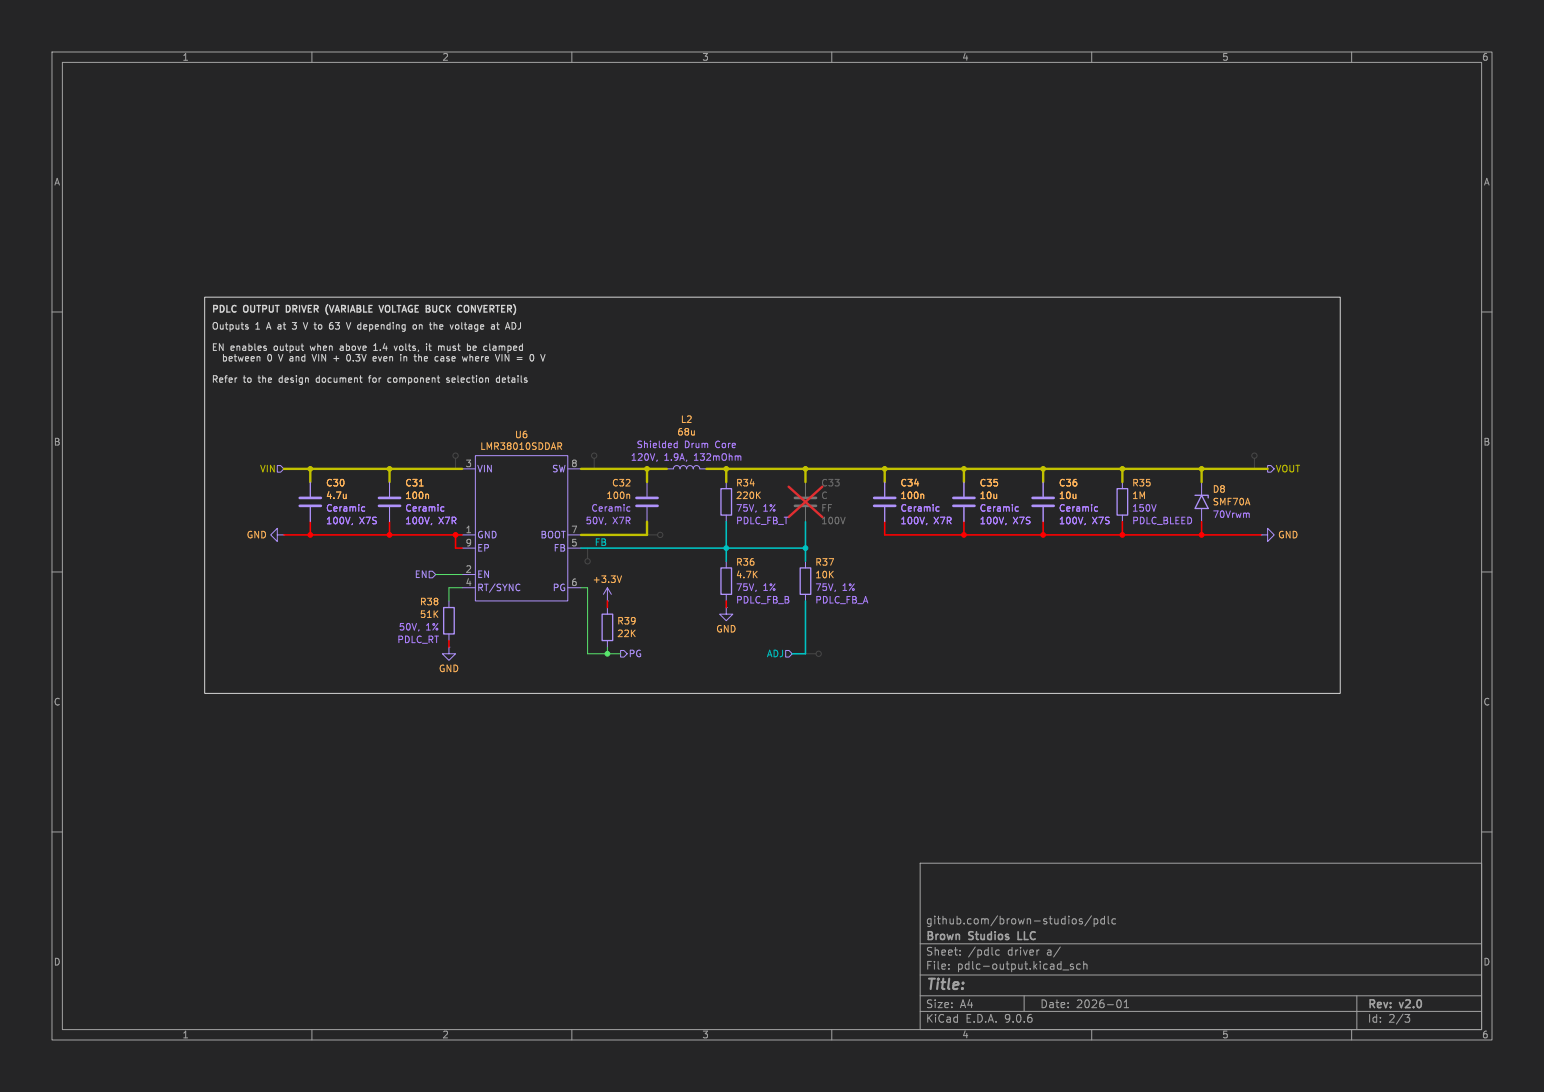
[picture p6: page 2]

PDLC OUTPUT DRIVER (VARIABLE VOLTAGE BUCK CONVERTER)

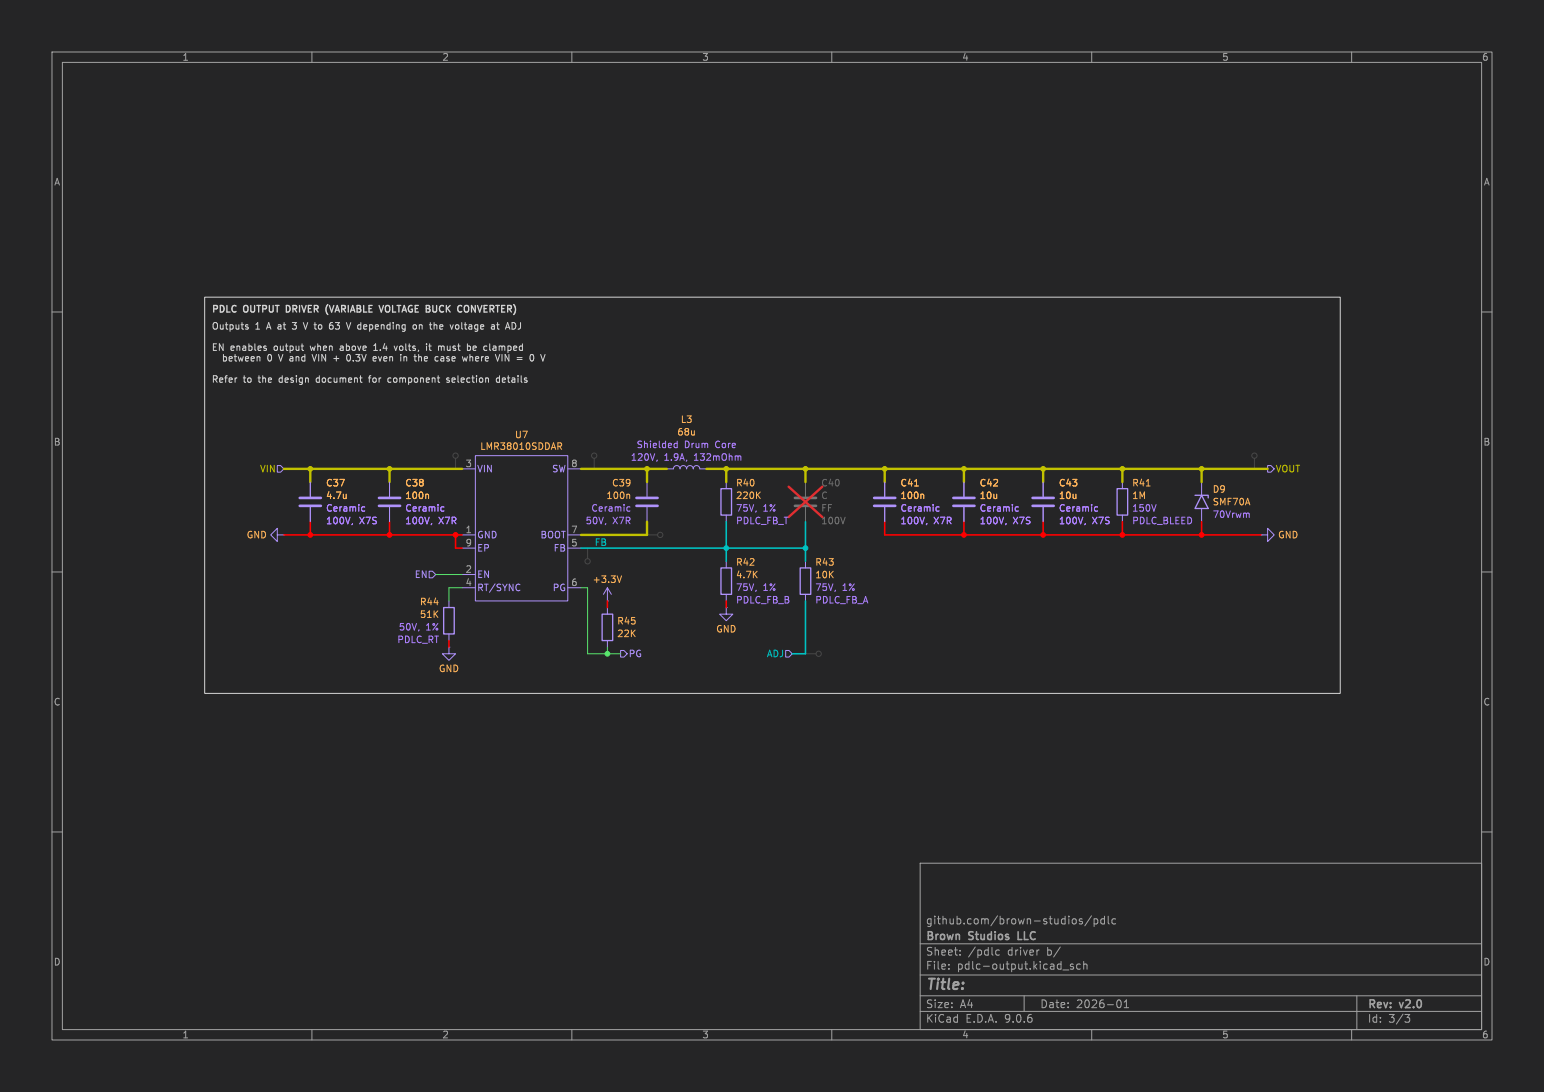
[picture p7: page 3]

PDLC OUTPUT DRIVER (VARIABLE VOLTAGE BUCK CONVERTER)

github.com/brown-studios/pdlc

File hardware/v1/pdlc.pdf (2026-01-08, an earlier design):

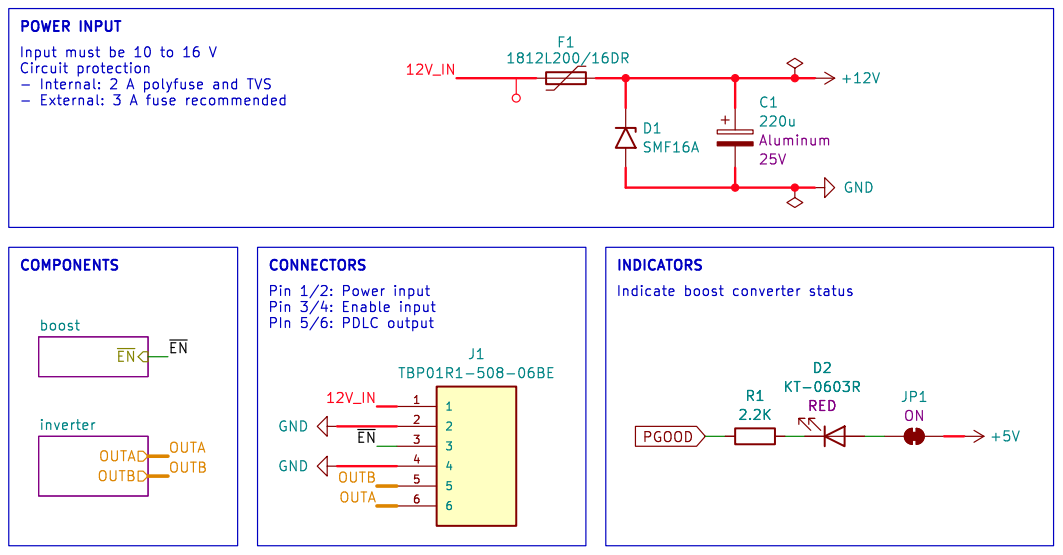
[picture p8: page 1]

POWER INPUT
Input must be 10 to 16 V Circuit protection

PGOOD OUTB OUTA OUTB

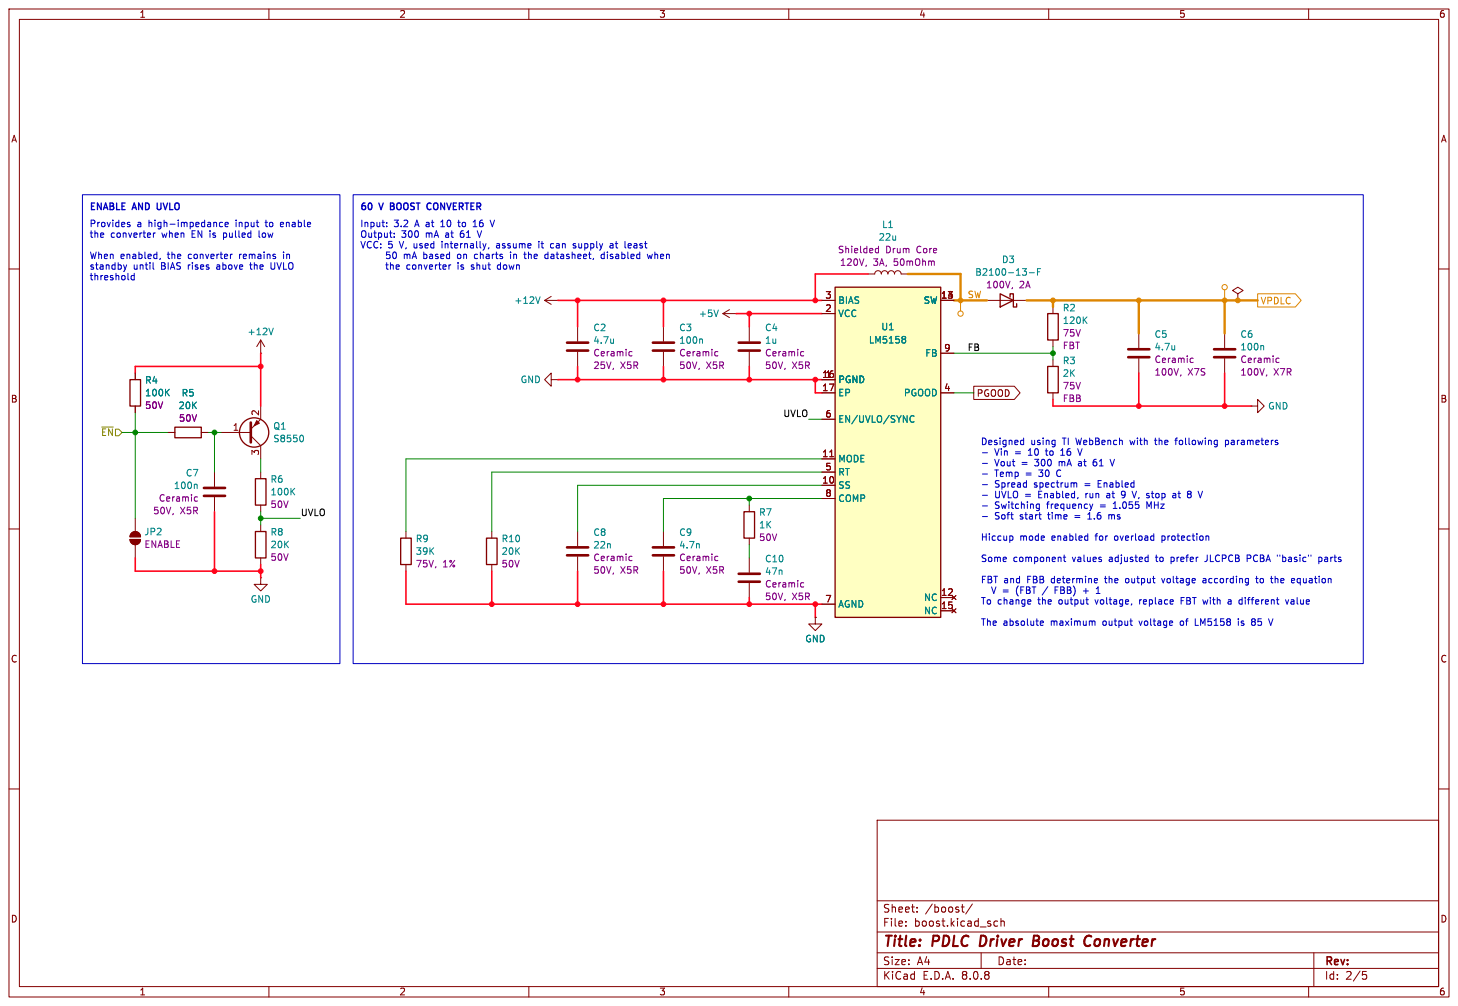
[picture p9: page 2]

60 V BOOST CONVERTER
Input: 3.2 A at 10 to 16 V Output: 300 mA at 61 V

standby until BIAS rises above the UVLO
threshold

- Vin = 10 to 16 V
- Vout = 300 mA at 61 V
- Temp = 30 C
- UVLO = Enabled, run at 9 V, stop at 8 V

Id: 2/5 Title: PDLC Driver Boost Converter File: boost.kicad_sch Sheet: /boost/

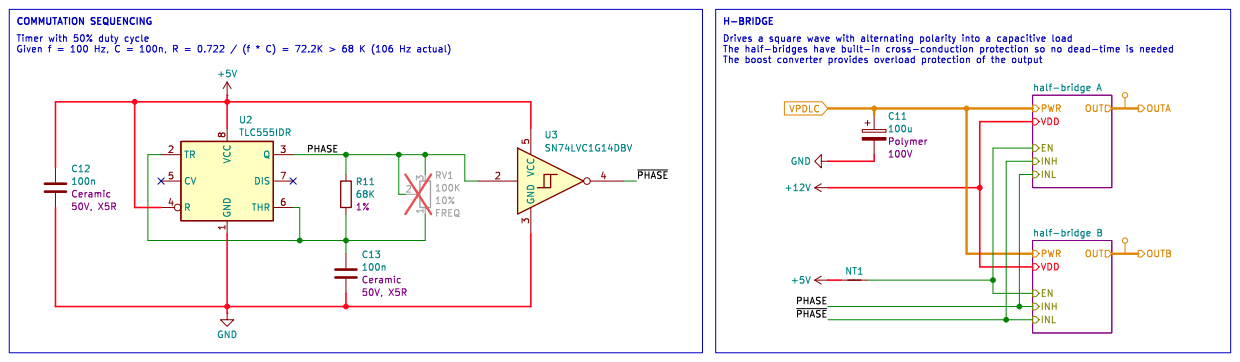
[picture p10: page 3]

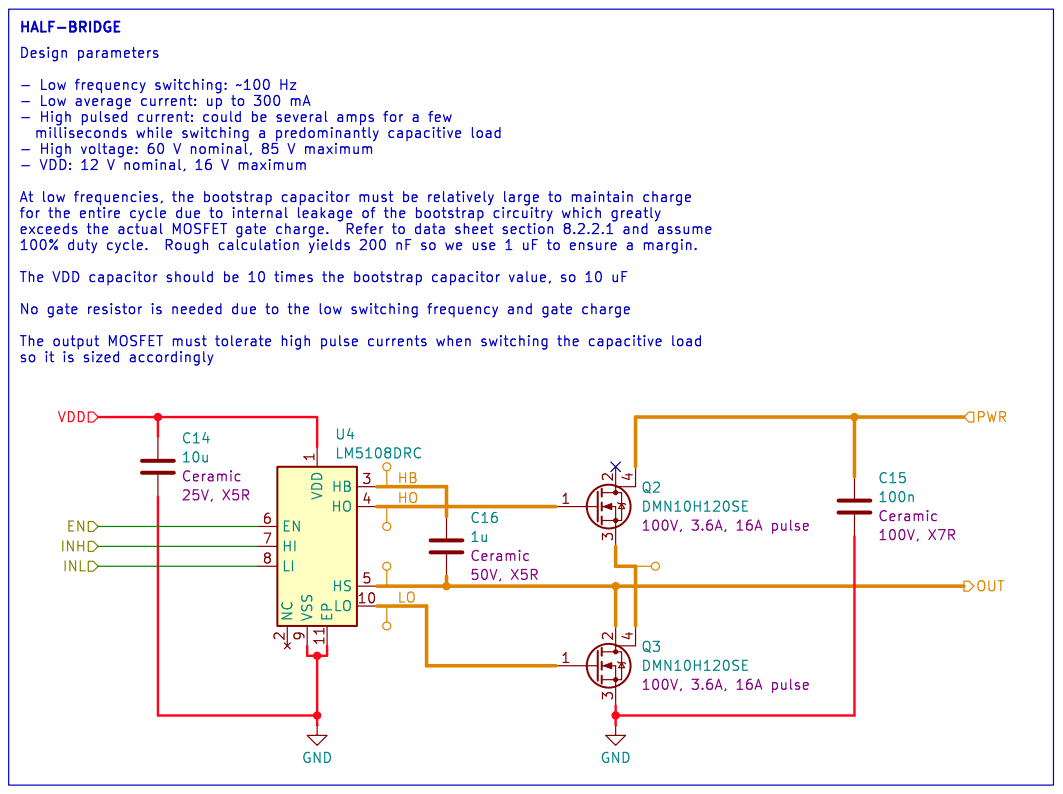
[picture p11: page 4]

HALF-BRIDGE Design parameters

so it is sized accordingly

Id: 4/5 Title: PDLC Driver Half Bridge

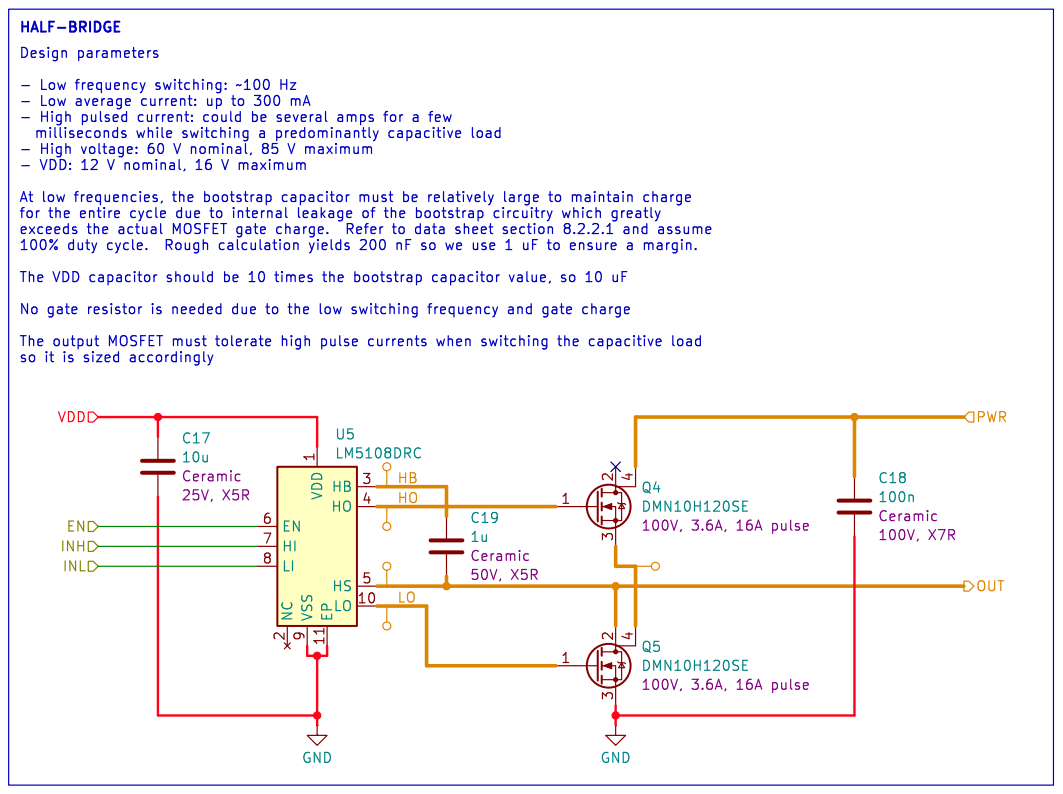
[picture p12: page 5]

HALF-BRIDGE Design parameters

so it is sized accordingly

Id: 5/5 Title: PDLC Driver Half Bridge

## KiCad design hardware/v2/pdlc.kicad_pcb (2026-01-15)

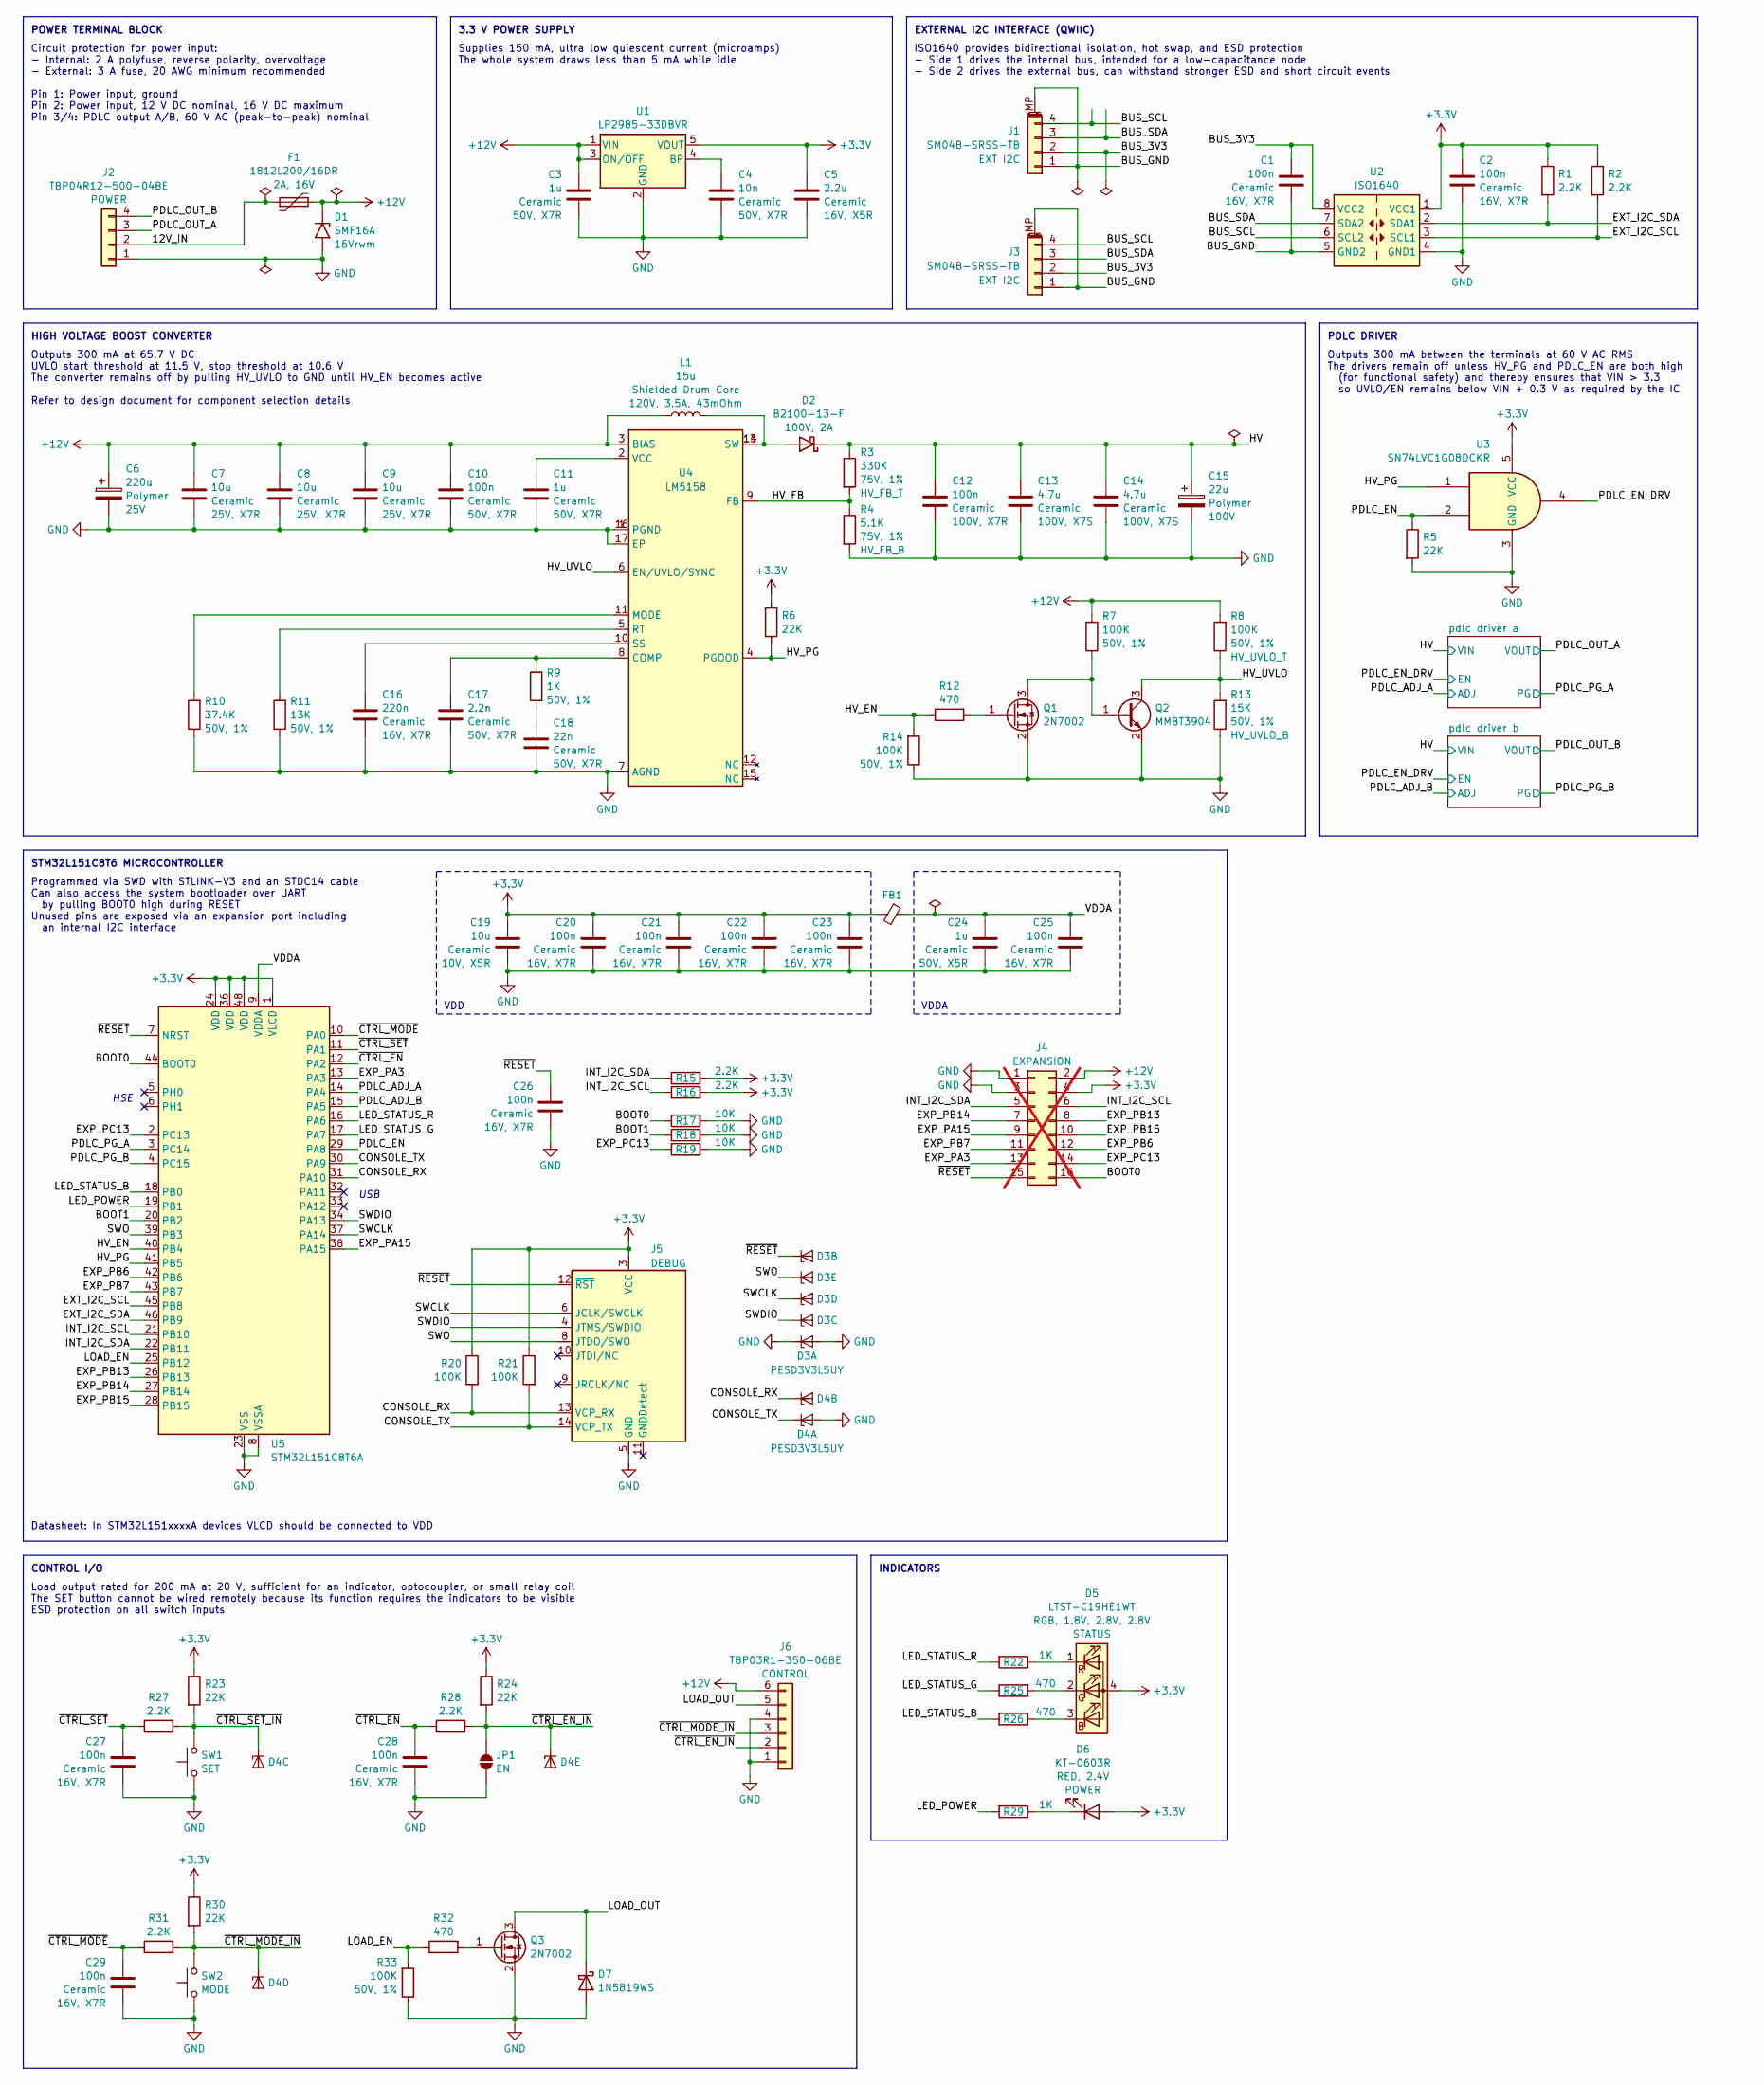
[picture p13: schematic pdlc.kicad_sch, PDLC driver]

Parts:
C1, C2, C20, C21, C22, C23, C25, C26, C27, C28, C29: 100n; C_0402_1005Metric; Rating 16V, X7R; LCSC C1525
C3, C11: 1u; C_0805_2012Metric; Rating 50V, X7R; LCSC C28323
C4: 10n; C_0402_1005Metric; Rating 50V, X7R; LCSC C15195
C5: 2.2u; C_0603_1608Metric; Rating 16V, X5R; LCSC C23630
C6: 220u; CP_Radial_D6.3mm_P2.50mm; Rating 25V; Part 2210250609R00; LCSC C2887216
C7, C8, C9: 10u; C_1210_3225Metric; Rating 25V, X7R; Part CL32B106KAJNNNE; LCSC C39232
C10: 100n; C_0603_1608Metric; Rating 50V, X7R; LCSC C14663
C12: 100n; C_1206_3216Metric; Rating 100V, X7R; Part CL31B104KCFNNNE; LCSC C1945
C13, C14: 4.7u; C_1210_3225Metric; Rating 100V, X7S; Part HMK325C7475KN-TE; LCSC C697607
C15: 22u; CP_Elec_6.3x9.9; Rating 100V; Part 2201010609TR; LCSC C19270543
C16: 220n; C_0402_1005Metric; Rating 16V, X7R; LCSC C16772
C17: 2.2n; C_0603_1608Metric; Rating 50V, X7R; LCSC C1604
C18: 22n; C_0402_1005Metric; Rating 50V, X7R; LCSC C1532
C19: 10u; C_0603_1608Metric; Rating 10V, X5R; LCSC C19702
C24: 1u; C_0603_1608Metric; Rating 50V, X5R; LCSC C15849
D1: SMF16A; D_SMF; Rating 16Vrwm; Part Alternative SMF16A-E3-08; LCSC C207257
D2: B2100-13-F; D_SMB; Rating 100V, 2A; LCSC C110479
D3, D4: PESD3V3L5UY; SOT-363_SC-70-6; LCSC C3021133
D5: LTST-C19HE1WT; LED_LiteOn_LTST-C19HE1WT; Rating RGB, 1.8V, 2.8V, 2.8V
D6: KT-0603R; LED_0603_1608Metric; Rating RED, 2.4V; LCSC C2286
D7: 1N5819WS; D_SOD-323; LCSC C191023
F1: 1812L200/16DR; 1812L; Rating 2A, 16V; LCSC C439873
FB1: 450mOhm; L_0603_1608Metric; Rating 600ohm@100Mhz, 200mA; Part GZ1608D601TF; LCSC C1002
J1, J3: SM04B-SRSS-TB; JST_SH_SM04B-SRSS-TB_1x04-1MP_P1.00mm_Horizontal; Part Alternative GT-A1002WRS-104SBT01; LCSC C160404
J2: TBP04R12-500-04BE; PhoenixContact_MSTBA_2,5_4-G_1x04_P5.00mm_Horizontal
J4: Conn_02x08_Odd_Even; PinSocket_2x08_P2.54mm_Vertical; not fitted
J5: Conn_ST_STDC14; SAMTEC_FTSH-107-01-L-DV-K-A; LCSC C5563894
J6: TBP03R1-350-06BE; PhoenixContact_MC_1,5_6-G-3.5_1x06_P3.50mm_Horizontal
JP1: SolderJumper_2_Open; SolderJumper-2_P1.3mm_Open_TrianglePad1.0x1.5mm
L1: 15u; WE-PD_1050P; Rating 120V, 3.5A, 43mOhm; Part 7447714150; LCSC C373521
Q1, Q3: 2N7002; SOT-23; LCSC C8545
Q2: MMBT3904; SOT-23; LCSC C20526
R1, R2, R15, R16, R27, R28, R31: 2.2K; R_0402_1005Metric; LCSC C25879
R3: 330K; R_0603_1608Metric; Rating 75V, 1%; LCSC C23137
R4: 5.1K; R_0603_1608Metric; Rating 75V, 1%; LCSC C23186
R5, R6, R23, R24, R30: 22K; R_0402_1005Metric; LCSC C25768
R7, R8, R14, R33: 100K; R_0402_1005Metric; Rating 50V, 1%; LCSC C25741
R9, R22, R29: 1K; R_0402_1005Metric; Rating 50V, 1%; LCSC C11702
R10: 37.4K; R_0402_1005Metric; Rating 50V, 1%; LCSC C25888
R11: 13K; R_0402_1005Metric; Rating 50V, 1%; LCSC C25754
R12, R25, R26, R32: 470; R_0402_1005Metric; LCSC C25117
R13: 15K; R_0402_1005Metric; Rating 50V, 1%; LCSC C25756
R17, R18, R19: 10K; R_0402_1005Metric; LCSC C25744
R20, R21: 100K; R_0402_1005Metric; LCSC C25741
SW1, SW2: SW_Push; SW_SPST_TS-1088-xR020; Part TS-1088-AR02016; LCSC C720477
U1: LP2985-33DBVR; SOT-23-5; LCSC C95414
U2: ISO1640; SOIC-8_3.9x4.9mm_P1.27mm; LCSC C5122339
U3: SN74LVC1G08DCKR; SOT-353_SC-70-5; LCSC C7832
U4: LM5158; LCSC C3188433
U5: STM32L151C8T6A; LQFP-48_7x7mm_P0.5mm; LCSC C95578

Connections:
+3.3V: C2.1, C5.2, C19.1, C20.1, C21.1, C22.1, C23.1, D5.4 (A), D6.2 (A), FB1.1, J4.4, J5.3 (VCC), R1.1, R2.1, R6.1, R15.2, R16.2, R20.1, R21.1, R23.1, R24.1, R30.1, U1.5 (VOUT), U2.1 (VCC1), U3.5 (VCC), U5.1 (VLCD), U5.24 (VDD), U5.36 (VDD), U5.48 (VDD); also elsewhere on the board
+12V: C3.1, C6.1, C7.1, C8.1, C9.1, C10.1, D1.1 (A1), F1.2, J4.2, J6.6, L1.2, R7.2, R8.2, U1.1 (VIN), U1.3 (ON/~OFF), U4.3 (BIAS)
/12V_IN: F1.1, J2.2
/BOOT0: J4.16, R17.1, U5.44 (BOOT0)
/BOOT1: R18.1, U5.20 (PB2)
/BUS_3V3: C1.1, J1.2, J3.2, U2.8 (VCC2)
/BUS_GND: C1.2, J1.1, J1.MP (MountPin), J3.1, J3.MP (MountPin), U2.5 (GND2)
/BUS_SCL: J1.4, J3.4, U2.6 (SCL2)
/BUS_SDA: J1.3, J3.3, U2.7 (SDA2)
/CONSOLE_RX: D4.3 (K2), J5.13 (VCP_RX), R20.2, U5.31 (PA10)
/CONSOLE_TX: D4.1 (K1), J5.14 (VCP_TX), R21.2, U5.30 (PA9)
/EXP_PA3: J4.13, U5.13 (PA3)
/EXP_PA15: J4.9, U5.38 (PA15)
/EXP_PB6: J4.12, U5.42 (PB6)
/EXP_PB7: J4.11, U5.43 (PB7)
/EXP_PB13: J4.8, U5.26 (PB13)
/EXP_PB14: J4.7, U5.27 (PB14)
/EXP_PB15: J4.10, U5.28 (PB15)
/EXP_PC13: J4.14, R19.1, U5.2 (PC13)
/EXT_I2C_SCL: R2.2, U2.3 (SCL1), U5.45 (PB8)
/EXT_I2C_SDA: R1.2, U2.2 (SDA1), U5.46 (PB9)
/HV: C12.1, C13.1, C14.1, C15.1, D2.1 (K), R3.1; also elsewhere on the board
/HV_EN: R12.1, R14.2, U5.40 (PB4)
/HV_FB: R3.2, R4.1, U4.9 (FB)
/HV_PG: R6.2, U3.1, U4.4 (PGOOD), U5.41 (PB5)
/HV_UVLO: Q2.3 (C), R8.1, R13.2, U4.6 (EN/UVLO/SYNC)
/INT_I2C_SCL: J4.6, R16.1, U5.21 (PB10)
/INT_I2C_SDA: J4.5, R15.1, U5.22 (PB11)
/LED_POWER: R29.2, U5.19 (PB1)
/LED_STATUS_B: R26.1, U5.18 (PB0)
/LED_STATUS_G: R25.1, U5.17 (PA7)
/LED_STATUS_R: R22.2, U5.16 (PA6)
/LOAD_EN: R32.1, R33.2, U5.25 (PB12)
/LOAD_OUT: D7.1 (K), J6.5, Q3.3 (D)
/PDLC_ADJ_A: U5.14 (PA4); also elsewhere on the board
/PDLC_ADJ_B: U5.15 (PA5); also elsewhere on the board
/PDLC_EN: R5.1, U3.2, U5.29 (PA8)
/PDLC_EN_DRV: U3.4; also elsewhere on the board
/PDLC_OUT_A: J2.3; also elsewhere on the board
/PDLC_OUT_B: J2.4; also elsewhere on the board
/PDLC_PG_A: U5.3 (PC14); also elsewhere on the board
/PDLC_PG_B: U5.4 (PC15); also elsewhere on the board
/SWCLK: D3.5 (K4), J5.6 (JCLK/SWCLK), U5.37 (PA14)
/SWDIO: D3.4 (K3), J5.4 (JTMS/SWDIO), U5.34 (PA13)
/SWO: D3.6 (K5), J5.8 (JTDO/SWO), U5.39 (PB3)
/VDDA: C24.1, C25.1, FB1.2, U5.9 (VDDA)
/~CTRL_EN_IN: D4.6 (K5), J6.2, JP1.2 (B), R24.2, R28.2
/~CTRL_EN: C28.1, R28.1, U5.12 (PA2)
/~CTRL_MODE_IN: D4.5 (K4), J6.3, R30.2, R31.2, SW2.2
/~CTRL_MODE: C29.1, R31.1, U5.10 (PA0)
/~CTRL_SET_IN: D4.4 (K3), R23.2, R27.2, SW1.2
/~CTRL_SET: C27.1, R27.1, U5.11 (PA1)
/~RESET: C26.1, D3.3 (K2), J4.15, J5.12 (~RST), U5.7 (NRST)
GND: C2.2, C3.2, C4.1, C5.1, C6.2, C7.2, C8.2, C9.2, C10.2, C11.2, C12.2, C13.2, C14.2, C15.2, C16.2, C17.2, C18.2, C19.2, C20.2, C21.2, C22.2, C23.2, C24.2, C25.2, C26.2, C27.2, C28.2, C29.2, D1.2 (A2), D3.1 (K1), D3.2 (A), D4.2 (A), D7.2 (A), J2.1, J4.1, J4.3, J5.5 (GND), J5.7 (GND), J6.1, J6.4, JP1.1 (A), Q1.2 (S), Q2.2 (E), Q3.2 (S), R4.2, R5.2, R10.1, R11.1, R13.1, R14.1, R17.2, R18.2, R19.2, R33.1, SW1.1, SW2.1, U1.2 (GND), U2.4 (GND1), U3.3 (GND), U4.1 (PGND), U4.7 (AGND), U4.16 (PGND), U4.17 (EP), U5.8 (VSSA), U5.23 (VSS), U5.35 (VSS), U5.47 (VSS); also elsewhere on the board
unnamed: C18.1, R9.1
unnamed: D2.2 (A), L1.1, U4.13 (SW), U4.14 (SW)
unnamed: D5.3 (BK), R26.2
unnamed: D5.2 (GK), R25.2
unnamed: D5.1 (RK), R22.1
unnamed: D6.1 (K), R29.1
unnamed: Q1.3 (D), Q2.1 (B), R7.1
unnamed: Q1.1 (G), R12.2
unnamed: Q3.1 (G), R32.2
unnamed: C4.2, U1.4 (BP)
unnamed: C17.1, R9.2, U4.8 (COMP)
unnamed: R10.2, U4.11 (MODE)
unnamed: R11.2, U4.5 (RT)
unnamed: C16.1, U4.10 (SS)
unnamed: C11.1, U4.2 (VCC)

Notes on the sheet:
STM32L151C8T6 MICROCONTROLLER
USB
Load output rated for 200 mA at 20 V, sufficient for an indicator, optocoupler, or small relay coil The SET button cannot be wired remotely because its function requires the indicators to be visible ESD protection on all switch inputs
HSE
Outputs 300 mA at 65.7 V DC UVLO start threshold at 11.5 V, stop threshold at 10.6 V The converter remains off by pulling HV_UVLO to GND until HV_EN becomes active Refer to design document for component selection details
VDDA
POWER TERMINAL BLOCK
ISO1640 provides bidirectional isolation, hot swap, and ESD protection - Side 1 drives the internal bus, intended for a low-capacitance node - Side 2 drives the external bus, can withstand stronger ESD and short circuit events
3.3 V POWER SUPPLY
Supplies 150 mA, ultra low quiescent current (microamps) The whole system draws less than 5 mA while idle
Circuit protection for power input: - Internal: 2 A polyfuse, reverse polarity, overvoltage - External: 3 A fuse, 20 AWG minimum recommended Pin 1: Power input, ground Pin 2: Power input, 12 V DC nominal, 16 V DC maximum Pin 3/4: PDLC output A/B, 60 V AC (peak-to-peak) nominal
Programmed via SWD with STLINK-V3 and an STDC14 cable Can also access the system bootloader over UART by pulling BOOT0 high during RESET Unused pins are exposed via an expansion port including an internal I2C interface
INDICATORS
Outputs 300 mA between the terminals at 60 V AC RMS The drivers remain off unless HV_PG and PDLC_EN are both high (for functional safety) and thereby ensures that VIN > 3.3 so UVLO/EN remains below VIN + 0.3 V as required by the IC
EXTERNAL I2C INTERFACE (QWIIC)
Datasheet: In STM32L151xxxxA devices VLCD should be connected to VDD
PDLC DRIVER
HIGH VOLTAGE BOOST CONVERTER
VDD
CONTROL I/O

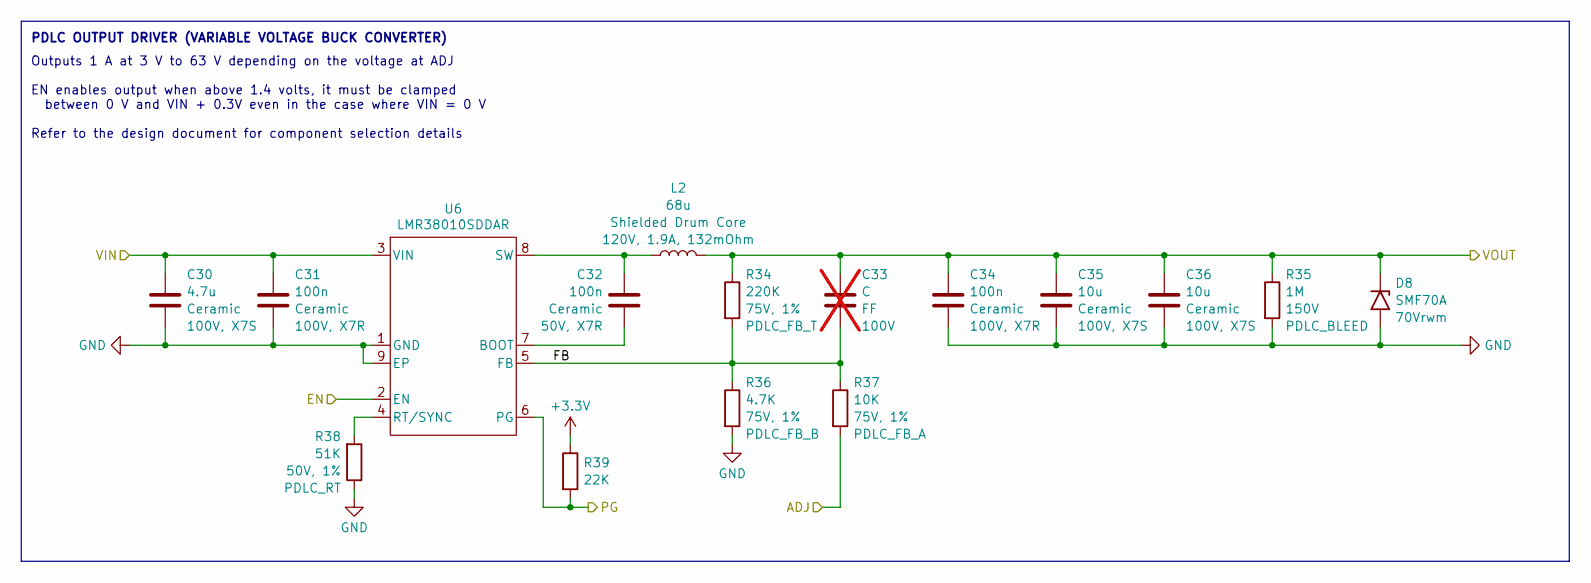
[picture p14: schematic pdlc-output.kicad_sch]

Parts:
C30: 4.7u; C_1210_3225Metric; Rating 100V, X7S; Part HMK325C7475KN-TE; LCSC C697607
C31, C34: 100n; C_1206_3216Metric; Rating 100V, X7R; Part CL31B104KCFNNNE; LCSC C1945
C32: 100n; C_0603_1608Metric; Rating 50V, X7R; LCSC C14663
C33: C; C_0603_1608Metric; Rating 100V; not fitted
C35, C36: 10u; C_1210_3225Metric; Rating 100V, X7S; Part GRM32EC72A106KE05L; LCSC C576517
D8: SMF70A; D_SMF; Rating 70Vrwm; LCSC C1976954
L2: 68u; WE-PD_1050P; Rating 120V, 1.9A, 132mOhm; Part 7447714680; LCSC C5364067
R34: 220K; R_0603_1608Metric; Rating 75V, 1%; LCSC C22961
R35: 1M; R_0805_2012Metric; Rating 150V; LCSC C17514
R36: 4.7K; R_0603_1608Metric; Rating 75V, 1%; LCSC C23162
R37: 10K; R_0603_1608Metric; Rating 75V, 1%; LCSC C25804
R38: 51K; R_0402_1005Metric; Rating 50V, 1%; LCSC C25794
R39: 22K; R_0402_1005Metric; LCSC C25768
U6: LMR38010SDDAR; TI_SO-PowerPAD-8; LCSC C5219310

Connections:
+3.3V: R39.1; also elsewhere on the board
/HV: C30.1, C31.1, U6.3 (VIN); also elsewhere on the board
/PDLC_ADJ_A: R37.2; also elsewhere on the board
/PDLC_EN_DRV: U6.2 (EN); also elsewhere on the board
/PDLC_OUT_A: C33.1, C34.1, C35.1, C36.1, D8.1 (A1), L2.2, R34.1, R35.1; also elsewhere on the board
/PDLC_PG_A: R39.2, U6.6 (PG); also elsewhere on the board
/pdlc driver a/FB: C33.2, R34.2, R36.1, R37.1, U6.5 (FB)
GND: C30.2, C31.2, C34.2, C35.2, C36.2, D8.2 (A2), R35.2, R36.2, R38.1, U6.1 (GND), U6.9 (EP); also elsewhere on the board
unnamed: C32.2, U6.7 (BOOT)
unnamed: R38.2, U6.4 (RT/SYNC)
unnamed: C32.1, L2.1, U6.8 (SW)

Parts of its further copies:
C37: 4.7u; C_1210_3225Metric; Rating 100V, X7S; Part HMK325C7475KN-TE; LCSC C697607
C38, C41: 100n; C_1206_3216Metric; Rating 100V, X7R; Part CL31B104KCFNNNE; LCSC C1945
C39: 100n; C_0603_1608Metric; Rating 50V, X7R; LCSC C14663
C40: C; C_0603_1608Metric; Rating 100V; not fitted
C42, C43: 10u; C_1210_3225Metric; Rating 100V, X7S; Part GRM32EC72A106KE05L; LCSC C576517
D9: SMF70A; D_SMF; Rating 70Vrwm; LCSC C1976954
L3: 68u; WE-PD_1050P; Rating 120V, 1.9A, 132mOhm; Part 7447714680; LCSC C5364067
R40: 220K; R_0603_1608Metric; Rating 75V, 1%; LCSC C22961
R41: 1M; R_0805_2012Metric; Rating 150V; LCSC C17514
R42: 4.7K; R_0603_1608Metric; Rating 75V, 1%; LCSC C23162
R43: 10K; R_0603_1608Metric; Rating 75V, 1%; LCSC C25804
R44: 51K; R_0402_1005Metric; Rating 50V, 1%; LCSC C25794
R45: 22K; R_0402_1005Metric; LCSC C25768
U7: LMR38010SDDAR; TI_SO-PowerPAD-8; LCSC C5219310

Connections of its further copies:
+3.3V: R45.1; also elsewhere on the board
/HV: C37.1, C38.1, U7.3 (VIN); also elsewhere on the board
/PDLC_ADJ_B: R43.2; also elsewhere on the board
/PDLC_EN_DRV: U7.2 (EN); also elsewhere on the board
/PDLC_OUT_B: C40.1, C41.1, C42.1, C43.1, D9.1 (A1), L3.2, R40.1, R41.1; also elsewhere on the board
/PDLC_PG_B: R45.2, U7.6 (PG); also elsewhere on the board
/pdlc driver b/FB: C40.2, R40.2, R42.1, R43.1, U7.5 (FB)
GND: C37.2, C38.2, C41.2, C42.2, C43.2, D9.2 (A2), R41.2, R42.2, R44.1, U7.1 (GND), U7.9 (EP); also elsewhere on the board
unnamed: C39.2, U7.7 (BOOT)
unnamed: R44.2, U7.4 (RT/SYNC)
unnamed: C39.1, L3.1, U7.8 (SW)

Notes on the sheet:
Outputs 1 A at 3 V to 63 V depending on the voltage at ADJ EN enables output when above 1.4 volts, it must be clamped between 0 V and VIN + 0.3V even in the case where VIN = 0 V Refer to the design document for component selection details
PDLC OUTPUT DRIVER (VARIABLE VOLTAGE BUCK CONVERTER)

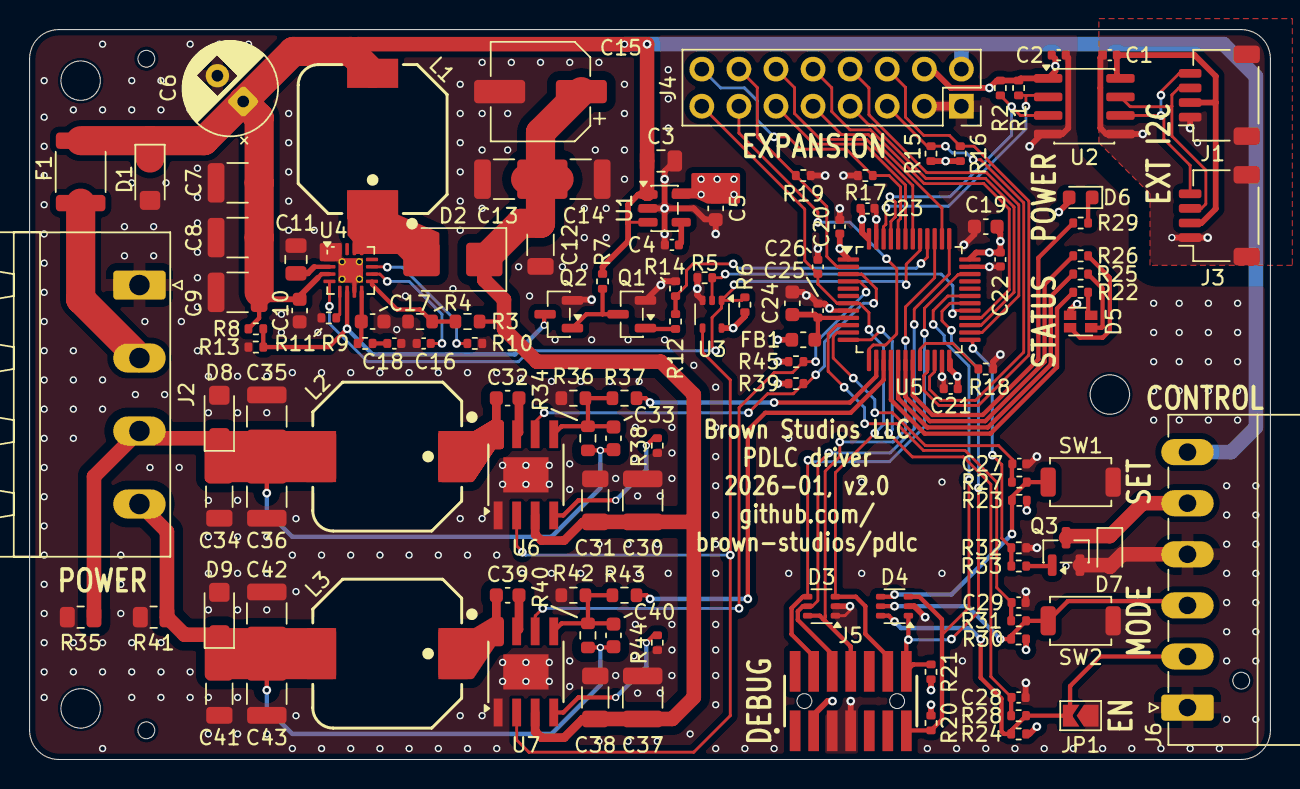
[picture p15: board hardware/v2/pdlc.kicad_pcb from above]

Board: 4 copper layers, 85.0 x 50.0 mm, 127 parts (0 on the bottom side), 77 nets.

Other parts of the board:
MP1, MP1#2, MP1#3: MountingHole_2.7mm_M2.5
TH1, TH1#2, TH1#3: JLCPCB_PCBA_Tooling_Hole

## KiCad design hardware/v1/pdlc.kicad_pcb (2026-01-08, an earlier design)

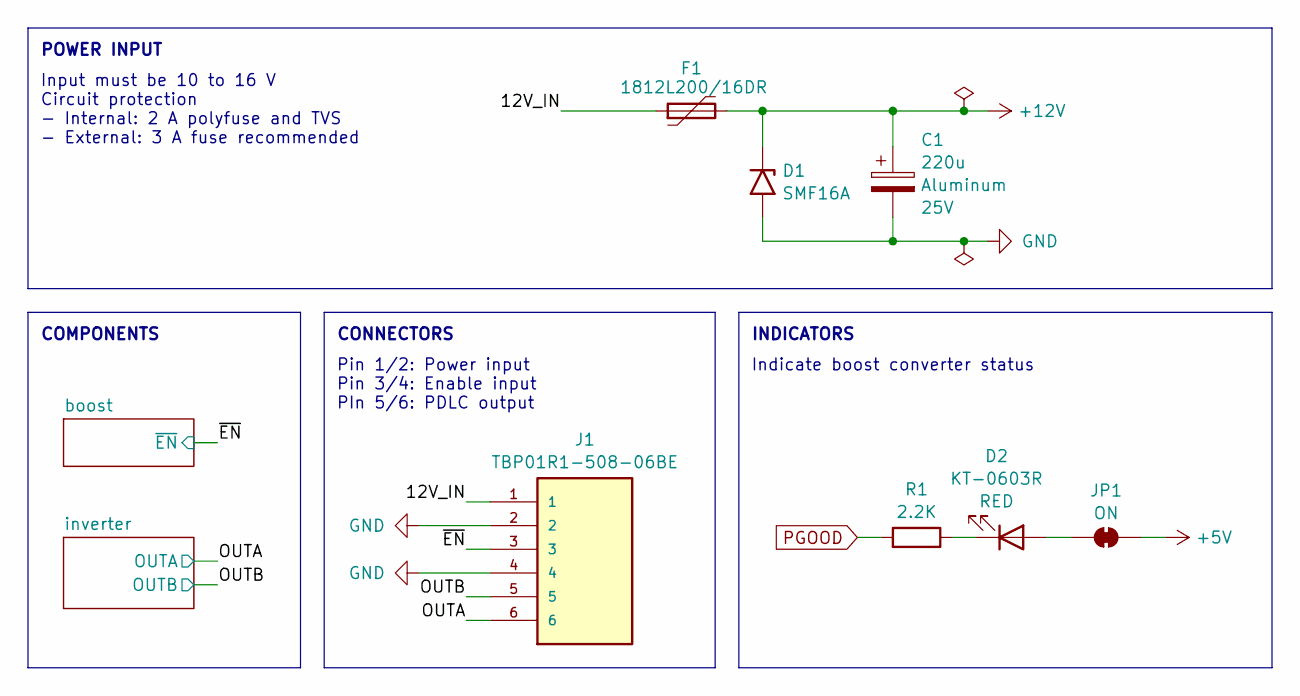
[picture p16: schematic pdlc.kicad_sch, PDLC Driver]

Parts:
C1: 220u; CP_Radial_D6.3mm_P2.50mm; Rating 25V; Part 2210250609R00; LCSC C2887216
D1: SMF16A; D_SMF; LCSC C207257
D2: KT-0603R; LED_0603_1608Metric_Pad1.05x0.95mm_HandSolder; Rating RED; LCSC C2286
F1: 1812L200/16DR; 1812L; LCSC C439873
J1: TBP01R1-508-06BE; CUI_TBP01R1-508-06BE
JP1: SolderJumper_2_Bridged; SolderJumper-2_P1.3mm_Bridged_RoundedPad1.0x1.5mm
R1: 2.2K; R_0603_1608Metric; LCSC C4190

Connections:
+5V: JP1.1 (A); also elsewhere on the board
+12V: C1.1, D1.1 (A1), F1.2; also elsewhere on the board
/12V_IN: F1.1, J1.1
/OUTA: J1.6; also elsewhere on the board
/OUTB: J1.5; also elsewhere on the board
/~EN: J1.3; also elsewhere on the board
GND: C1.2, D1.2 (A2), J1.2, J1.4; also elsewhere on the board
unnamed: D2.2 (A), JP1.2 (B)
unnamed: D2.1 (K), R1.1
PGOOD: R1.2; also elsewhere on the board

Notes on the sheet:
POWER INPUT
Indicate boost converter status
CONNECTORS
INDICATORS
COMPONENTS
Pin 1/2: Power input Pin 3/4: Enable input PIn 5/6: PDLC output
Input must be 10 to 16 V Circuit protection - Internal: 2 A polyfuse and TVS - External: 3 A fuse recommended

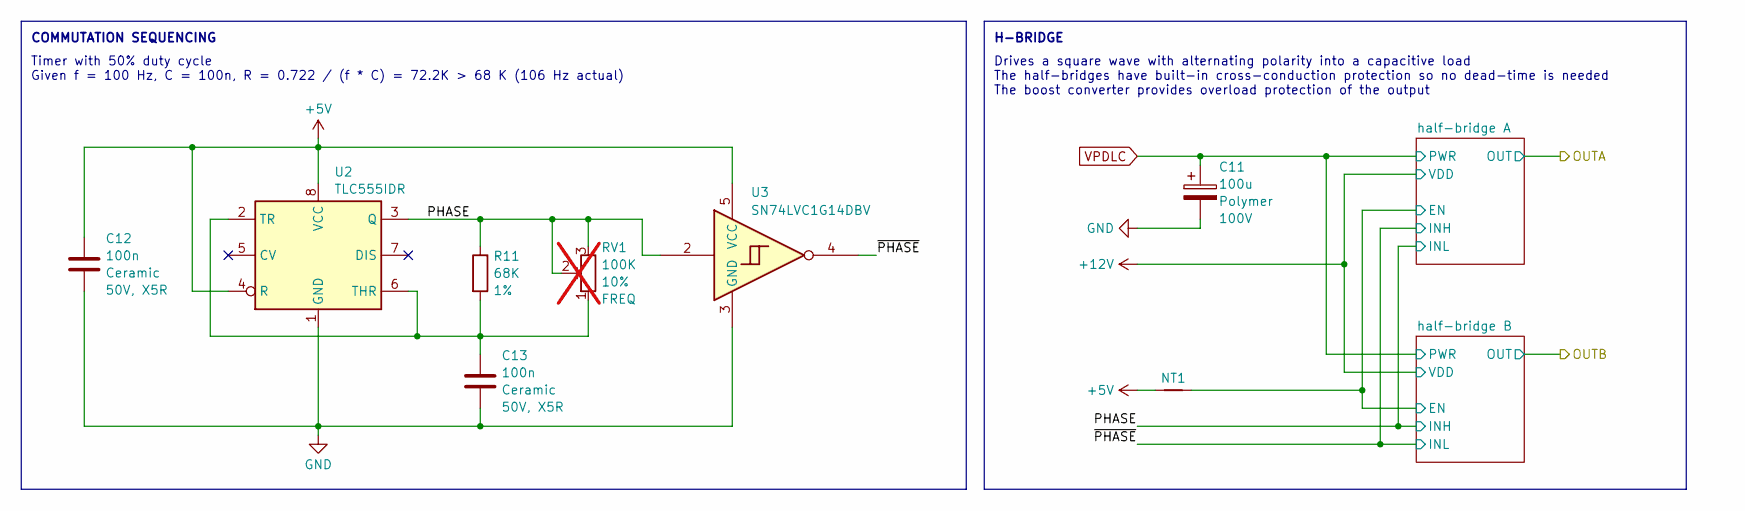
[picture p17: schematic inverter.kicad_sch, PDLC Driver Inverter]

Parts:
C11: 100u; CP_Radial_D10.0mm_P5.00mm; Rating 100V; Part 1011001013R00; LCSC C2887236
C12, C13: 100n; C_0603_1608Metric; Rating 50V, X5R; LCSC C14663
NT1: NetTie_2; NetTie-2_SMD_Pad0.2mm
R11: 68K; R_0603_1608Metric; Rating 1%; LCSC C23231
RV1: 100K; TRIM_3362P-1-502LF; Rating 10%; Part 3362P-1-104LF; not fitted
U2: TLC555IDR; SOIC-8_3.9x4.9mm_P1.27mm; LCSC C6987
U3: SN74LVC1G14DBV; SOT-23-5; LCSC C7835

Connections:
+5V: C12.1, NT1.1, U2.4 (R), U2.8 (VCC), U3.5 (VCC); also elsewhere on the board
/inverter/PHASE: R11.1, RV1.2, RV1.3, U2.3 (Q), U3.2; also elsewhere on the board
/inverter/half-bridge A/EN: NT1.2; also elsewhere on the board
/inverter/~PHASE: U3.4; also elsewhere on the board
GND: C11.2, C12.2, C13.2, U2.1 (GND), U3.3 (GND); also elsewhere on the board
unnamed: C13.1, R11.2, RV1.1, U2.2 (TR), U2.6 (THR)
VPDLC: C11.1; also elsewhere on the board

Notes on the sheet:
H-BRIDGE
Drives a square wave with alternating polarity into a capacitive load The half-bridges have built-in cross-conduction protection so no dead-time is needed The boost converter provides overload protection of the output
COMMUTATION SEQUENCING
Timer with 50% duty cycle Given f = 100 Hz, C = 100n, R = 0.722 / (f * C) = 72.2K > 68 K (106 Hz actual)

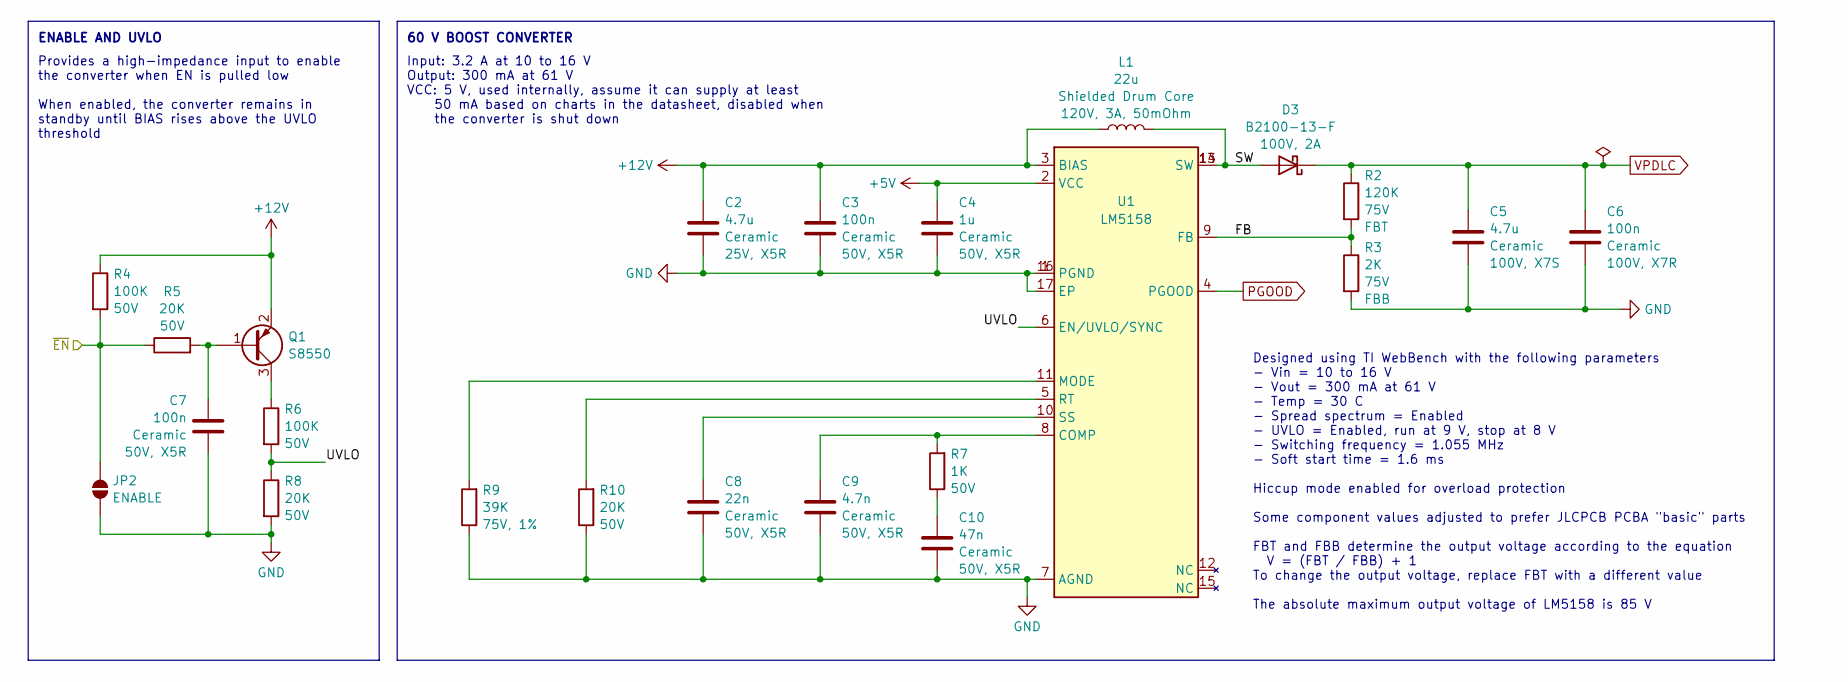
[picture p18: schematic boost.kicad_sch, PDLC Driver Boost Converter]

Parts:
C2: 4.7u; C_0805_2012Metric; Rating 25V, X5R; LCSC C1779
C3: 100n; C_0603_1608Metric; Rating 50V, X5R; LCSC C14663
C4: 1u; C_0603_1608Metric; Rating 50V, X5R; LCSC C15849
C5: 4.7u; C_1210_3225Metric; Rating 100V, X7S; LCSC C2803397
C6: 100n; C_0805_2012Metric; Rating 100V, X7R; LCSC C28233
C7: 100n; C_0402_1005Metric; Rating 50V, X5R; LCSC C307331
C8: 22n; C_0402_1005Metric; Rating 50V, X5R; LCSC C1532
C9: 4.7n; C_0402_1005Metric; Rating 50V, X5R; LCSC C1538
C10: 47n; C_0603_1608Metric; Rating 50V, X5R; LCSC C1622
D3: B2100-13-F; D_SMB; Rating 100V, 2A; LCSC C110479
JP2: SolderJumper_2_Open; SolderJumper-2_P1.3mm_Open_TrianglePad1.0x1.5mm
L1: 22u; WE-PD_1050P; Rating 120V, 3A, 50mOhm; Part 7447714220; LCSC C2651173
Q1: S8550; SOT-23; LCSC C105432
R2: 120K; R_0603_1608Metric; Rating 75V; LCSC C25808
R3: 2K; R_0603_1608Metric; Rating 75V; LCSC C22975
R4, R6: 100K; R_0402_1005Metric; Rating 50V; LCSC C25741
R5, R8, R10: 20K; R_0402_1005Metric; Rating 50V; LCSC C25765
R7: 1K; R_0402_1005Metric; Rating 50V; LCSC C11702
R9: 39K; R_0603_1608Metric; Rating 75V, 1%; LCSC C23153
U1: LM5158; LCSC C3188433

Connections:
+5V: C4.1, U1.2 (VCC); also elsewhere on the board
+12V: C2.1, C3.1, L1.1, Q1.2 (E), R4.1, U1.3 (BIAS); also elsewhere on the board
/boost/FB: R2.2, R3.1, U1.9 (FB)
/boost/SW: D3.2 (A), L1.2, U1.13 (SW), U1.14 (SW)
/boost/UVLO: R6.2, R8.1, U1.6 (EN/UVLO/SYNC)
/~EN: JP2.1 (A), R4.2, R5.1; also elsewhere on the board
GND: C2.2, C3.2, C4.2, C5.2, C6.2, C7.2, C8.2, C9.2, C10.2, JP2.2 (B), R3.2, R8.2, R9.1, R10.1, U1.1 (PGND), U1.7 (AGND), U1.16 (PGND), U1.17 (EP); also elsewhere on the board
unnamed: C10.1, R7.1
unnamed: C7.1, Q1.1 (B), R5.2
unnamed: Q1.3 (C), R6.1
unnamed: C9.1, R7.2, U1.8 (COMP)
unnamed: R9.2, U1.11 (MODE)
unnamed: R10.2, U1.5 (RT)
unnamed: C8.1, U1.10 (SS)
PGOOD: U1.4 (PGOOD); also elsewhere on the board
VPDLC: C5.1, C6.1, D3.1 (K), R2.1; also elsewhere on the board

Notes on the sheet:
60 V BOOST CONVERTER
Provides a high-impedance input to enable the converter when EN is pulled low When enabled, the converter remains in standby until BIAS rises above the UVLO threshold
Designed using TI WebBench with the following parameters - Vin = 10 to 16 V - Vout = 300 mA at 61 V - Temp = 30 C - Spread spectrum = Enabled - UVLO = Enabled, run at 9 V, stop at 8 V - Switching frequency = 1.055 MHz - Soft start time = 1.6 ms Hiccup mode enabled for overload protection Some compo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
ENABLE AND UVLO
Input: 3.2 A at 10 to 16 V Output: 300 mA at 61 V VCC: 5 V, used internally, assume it can supply at least 50 mA based on charts in the datasheet, disabled when the converter is shut down

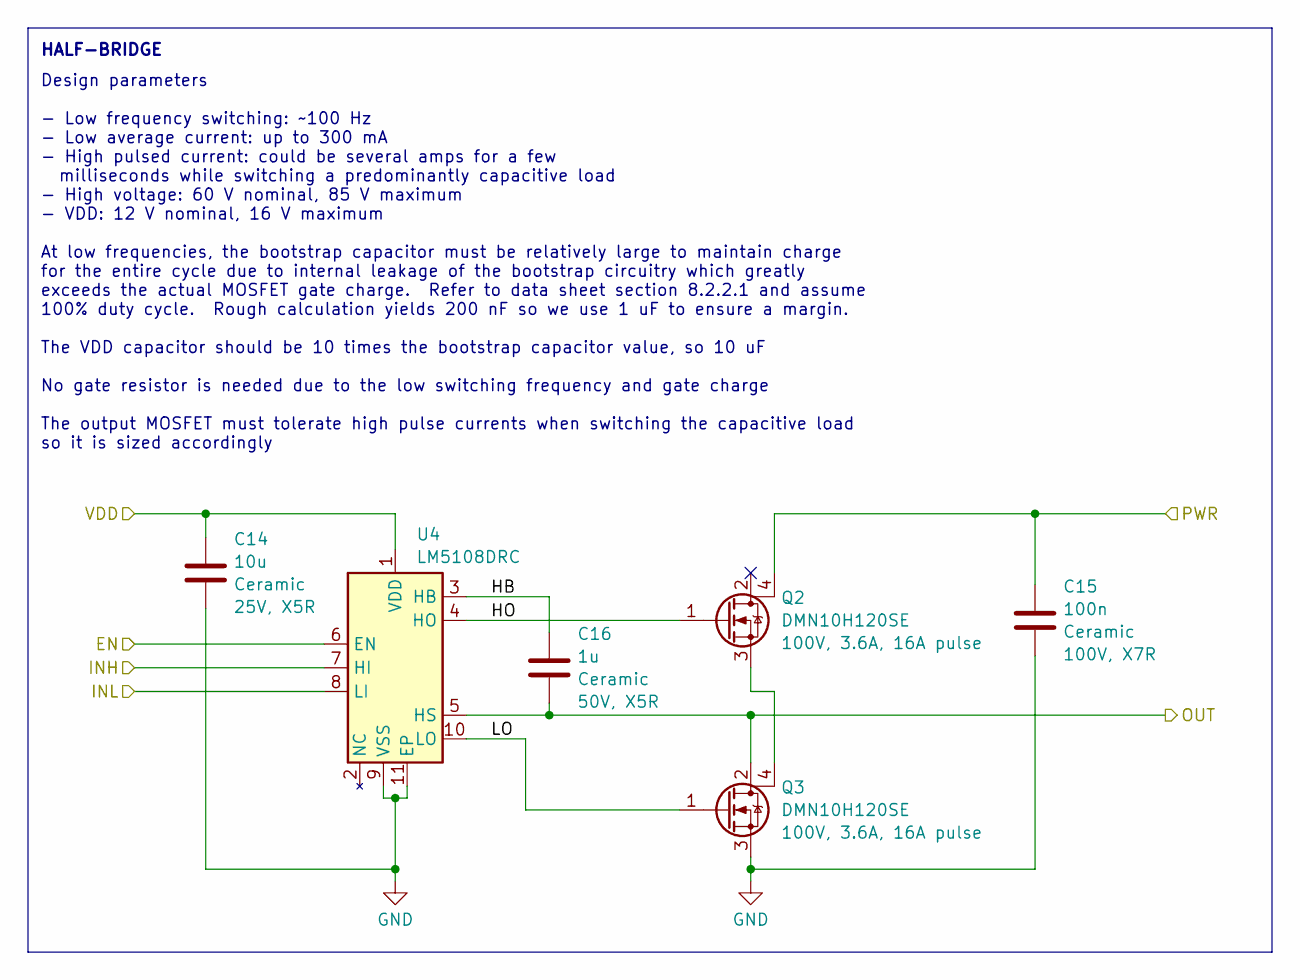
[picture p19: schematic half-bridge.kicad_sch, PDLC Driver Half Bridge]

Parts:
C14: 10u; C_0603_1608Metric; Rating 25V, X5R; LCSC C96446
C15: 100n; C_0805_2012Metric; Rating 100V, X7R; LCSC C28233
C16: 1u; C_0603_1608Metric; Rating 50V, X5R; LCSC C15849
Q2, Q3: DMN10H120SE; SOT-223; Rating 100V, 3.6A, 16A pulse; LCSC C460989
U4: LM5108DRC; VSON-10-1EP_3x3mm_P0.5mm_EP1.65x2.4mm; LCSC C2676946

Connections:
+12V: C14.1, U4.1 (VDD); also elsewhere on the board
/OUTA: C16.2, Q3.2 (D), U4.5 (HS); also elsewhere on the board
/inverter/PHASE: U4.8 (LI); also elsewhere on the board
/inverter/half-bridge A/EN: U4.6 (EN); also elsewhere on the board
/inverter/half-bridge A/HB: C16.1, U4.3 (HB)
/inverter/half-bridge A/HO: Q2.1 (G), U4.4 (HO)
/inverter/half-bridge A/LO: Q3.1 (G), U4.10 (LO)
/inverter/~PHASE: U4.7 (HI); also elsewhere on the board
GND: C14.2, C15.2, Q3.3 (S), U4.9 (VSS), U4.11 (EP); also elsewhere on the board
unnamed: Q2.3 (S), Q3.4 (D)
VPDLC: C15.1, Q2.4 (D); also elsewhere on the board

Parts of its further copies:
C17: 10u; C_0603_1608Metric; Rating 25V, X5R; LCSC C96446
C18: 100n; C_0805_2012Metric; Rating 100V, X7R; LCSC C28233
C19: 1u; C_0603_1608Metric; Rating 50V, X5R; LCSC C15849
Q4, Q5: DMN10H120SE; SOT-223; Rating 100V, 3.6A, 16A pulse; LCSC C460989
U5: LM5108DRC; VSON-10-1EP_3x3mm_P0.5mm_EP1.65x2.4mm; LCSC C2676946

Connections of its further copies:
+12V: C17.1, U5.1 (VDD); also elsewhere on the board
/OUTB: C19.2, Q5.2 (D), U5.5 (HS); also elsewhere on the board
/inverter/PHASE: U5.7 (HI); also elsewhere on the board
/inverter/half-bridge A/EN: U5.6 (EN); also elsewhere on the board
/inverter/half-bridge B/HB: C19.1, U5.3 (HB)
/inverter/half-bridge B/HO: Q4.1 (G), U5.4 (HO)
/inverter/half-bridge B/LO: Q5.1 (G), U5.10 (LO)
/inverter/~PHASE: U5.8 (LI); also elsewhere on the board
GND: C17.2, C18.2, Q5.3 (S), U5.9 (VSS), U5.11 (EP); also elsewhere on the board
unnamed: Q4.3 (S), Q5.4 (D)
VPDLC: C18.1, Q4.4 (D); also elsewhere on the board

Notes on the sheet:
Design parameters - Low frequency switching: ~100 Hz - Low average current: up to 300 mA - High pulsed current: could be several amps for a few milliseconds while switching a predominantly capacitive load - High voltage: 60 V nominal, 85 V maximum - VDD: 12 V nominal, 16 V maximum At low frequencie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
HALF-BRIDGE

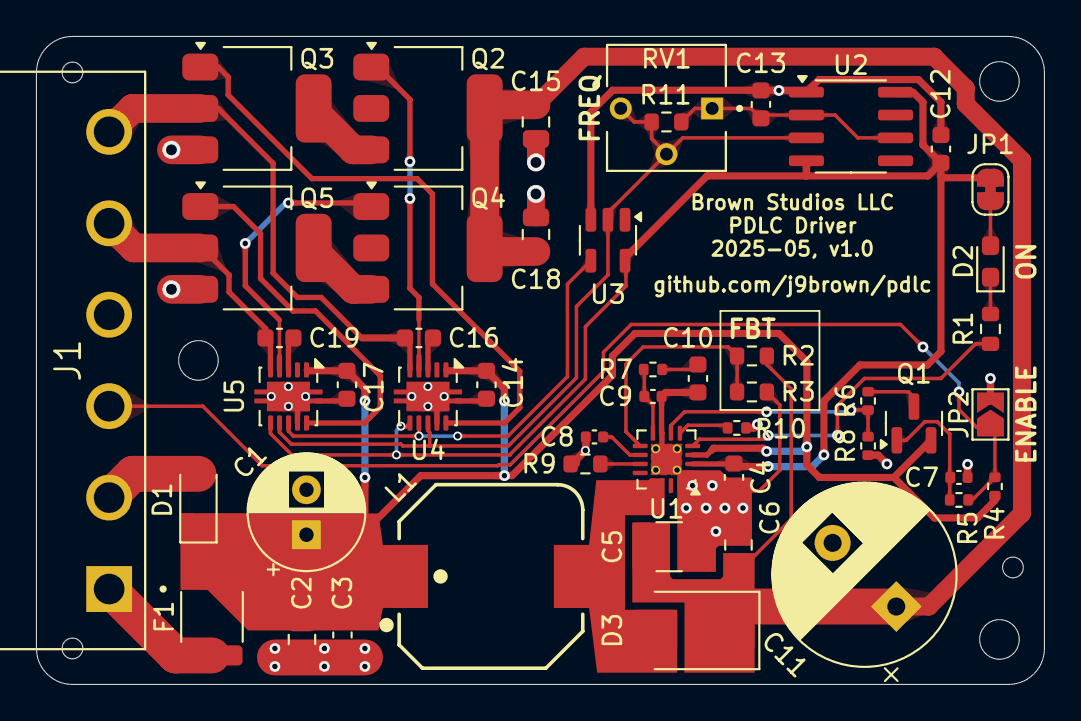
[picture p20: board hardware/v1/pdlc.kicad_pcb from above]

Board: 2 copper layers, 56.0 x 36.0 mm, 56 parts (0 on the bottom side), 33 nets.

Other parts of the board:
H1, H1#2, H2: MountingHole_2.2mm_M2
TH1, TH3, TH4: JLCPCB_PCBA_Tooling_Hole

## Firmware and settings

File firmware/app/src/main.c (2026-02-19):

#include <zephyr/drivers/gpio.h>
#include <zephyr/drivers/pwm.h>
#include <zephyr/drivers/watchdog.h>
#include <zephyr/kernel.h>
#include <zephyr/logging/log.h>

#include "control.h"
#include "pdlc.h"
#include "power_indicator.h"
#include "status_indicator.h"

LOG_MODULE_REGISTER(app);

#define WATCHDOG_TIMEOUT_MS (1000)
static const struct device *watchdog_dev = DEVICE_DT_GET(DT_NODELABEL(iwdg));

STATUS_INDICATOR_PATTERN_LOOP(status_indicator_pattern_generic_error, 0,
    STATUS_INDICATOR_PATTERN_ENTRY(STATUS_INDICATOR_HUE_RED, 2, 2, 1));

STATUS_INDICATOR_PATTERN_LOOP(status_indicator_pattern_control_error, 4,
    STATUS_INDICATOR_PATTERN_ENTRY(STATUS_INDICATOR_HUE_MAGENTA, 1, 3, STATUS_INDICATOR_PATTERN_PARAM_CYCLES));

STATUS_INDICATOR_PATTERN_LOOP(status_indicator_pattern_pdlc_error, 4,
    STATUS_INDICATOR_PATTERN_ENTRY(STATUS_INDICATOR_HUE_RED, 1, 3, STATUS_INDICATOR_PATTERN_PARAM_CYCLES));

static void show_error(int err) {
    switch (ERROR_CATEGORY(err)) {
        case ERROR_CATEGORY(CONTROL_ERROR_FIRST_):
            status_indicator_pattern(status_indicator_pattern_control_error, ERROR_INDEX(err));
            break;
        case ERROR_CATEGORY(PDLC_ERROR_FIRST_):
            status_indicator_pattern(status_indicator_pattern_pdlc_error, ERROR_INDEX(err));
            break;
        default:
            status_indicator_pattern(status_indicator_pattern_generic_error, 0);
            break;
    }
}

static void show_status(struct pdlc_status status) {
    switch (status.state) {
        case PDLC_STATE_IDLE:
            status_indicator_off();
            break;
        case PDLC_STATE_WAIT_FOR_HV_GOOD:
        case PDLC_STATE_WAIT_FOR_HV_STEADY:
        case PDLC_STATE_WAIT_FOR_OUTPUT_GOOD:
        case PDLC_STATE_WAIT_FOR_OUTPUT_STEADY:
            status_indicator_on(STATUS_INDICATOR_HUE_YELLOW);
            break;
        case PDLC_STATE_RUN:
            status_indicator_on(STATUS_INDICATOR_HUE_GREEN);
            break;
        case PDLC_STATE_HICCUP:
        case PDLC_STATE_FAULT:
            show_error(-status.error);
            break;
    }
}

static int setup(void) {
    int err;
    struct wdt_timeout_cfg watchdog_cfg = {
        .window = {
            .min = 0,
            .max = WATCHDOG_TIMEOUT_MS,
        },
        .callback = NULL,
        .flags = WDT_FLAG_RESET_SOC,
    };
    if ((err = wdt_install_timeout(watchdog_dev, &watchdog_cfg))) {
        return err;
    }
    if ((err = wdt_setup(watchdog_dev, WDT_OPT_PAUSE_HALTED_BY_DBG))) {
        return err;
    }
    if ((err = control_init())) {
        return err;
    }
    if ((err = pdlc_init())) {
        return err;
    }
    return 0;
}

static void loop(void) {
    static bool on;
    static enum control_action action_pending;
    enum control_action action = control_get_action();

    if (action != action_pending) {
        action_pending = action;
        switch (control_get_action()) {
            case CONTROL_ACTION_PRESS_MODE:
                LOG_INF("Control: CONTROL_ACTION_PRESS_MODE");
                on = !on;
                break;
            case CONTROL_ACTION_PRESS_SET:
                LOG_INF("Control: CONTROL_ACTION_PRESS_SET");
                break;
            case CONTROL_ACTION_LONG_HOLD_SET:
                LOG_INF("Control: CONTROL_ACTION_LONG_HOLD_SET");
                // todo: factory reset
                break;
            default:
                break;
        }
    }

    const unsigned scale = 256;
    const unsigned transition = 1000;
    struct pdlc_status status = pdlc_poll(on && control_get_enable() ? scale : 0, transition);
    show_status(status);
}

int main(void) {
    int err;
    if ((err = setup())) {
        status_indicator_on(STATUS_INDICATOR_HUE_RED);
        return err;
    }
    power_indicator_pulse();

    while (true) {
        if ((err = wdt_feed(watchdog_dev, 0))) {
            return err;
        }
        loop();
        k_msleep(10);
    }
    return 0;
}

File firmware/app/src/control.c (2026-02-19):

#include <errno.h>
#include <zephyr/drivers/gpio.h>
#include <zephyr/kernel.h>
#include <zephyr/sys/atomic.h>

#include "control.h"

#define ZEPHYR_USER_NODE DT_PATH(zephyr_user)
static const struct gpio_dt_spec control_mode_gpio = GPIO_DT_SPEC_GET(ZEPHYR_USER_NODE, control_mode_gpios);
static const struct gpio_dt_spec control_set_gpio = GPIO_DT_SPEC_GET(ZEPHYR_USER_NODE, control_set_gpios);
static const struct gpio_dt_spec control_en_gpio = GPIO_DT_SPEC_GET(ZEPHYR_USER_NODE, control_en_gpios);

#define CONTROL_DEBOUNCE_MS (10)
#define CONTROL_LONG_HOLD_MS (10000)

static struct gpio_callback control_gpio_callback;

static atomic_t control_action_pending;
static atomic_t control_action_current;
static atomic_t control_enable_pending;
static atomic_t control_enable_current;

static void control_work_handler(struct k_work* work);
K_WORK_DELAYABLE_DEFINE(control_work, control_work_handler);

static void control_gpio_handler(const struct device *port, struct gpio_callback *cb, gpio_port_pins_t pins) {
    gpio_port_value_t value = 0;
    gpio_port_get(port, &value);
    bool control_mode = IS_BIT_SET(value, control_mode_gpio.pin);
    bool control_set = IS_BIT_SET(value, control_set_gpio.pin);
    bool control_en = IS_BIT_SET(value, control_en_gpio.pin);
    enum control_action action;
    if (control_mode && !control_set) {
        action = CONTROL_ACTION_PRESS_MODE;
    } else if (control_set && !control_mode) {
        action = CONTROL_ACTION_PRESS_SET;
    } else {
        action = CONTROL_ACTION_RELEASE;
    }
    atomic_set(&control_action_pending, action);
    atomic_set(&control_enable_pending, control_en);
    k_work_reschedule(&control_work, K_MSEC(CONTROL_DEBOUNCE_MS));
}

static void control_work_handler(struct k_work* work) {
    enum control_action action = atomic_get(&control_action_pending);
    bool reschedule_for_hold;
    switch (action) {
        case CONTROL_ACTION_PRESS_SET:
            reschedule_for_hold = atomic_cas(&control_action_pending, action, CONTROL_ACTION_LONG_HOLD_SET);
            break;
        default:
            reschedule_for_hold = false;
            break;
    }
    if (reschedule_for_hold) {
        k_work_reschedule(&control_work, K_MSEC(CONTROL_LONG_HOLD_MS));
    }

    atomic_set(&control_action_current, action);
    atomic_set(&control_enable_current, atomic_get(&control_enable_pending));
}

int control_init(void) {
    int err;
    const struct device *port = control_mode_gpio.port;
    if (port != control_set_gpio.port || port != control_en_gpio.port) {
        return -EIO;
    }
    if (!device_is_ready(port)) {
        return -ENODEV;
    }
    gpio_init_callback(&control_gpio_callback, control_gpio_handler,
        BIT(control_set_gpio.pin) | BIT(control_mode_gpio.pin) | BIT(control_en_gpio.pin));

    if ((err = gpio_pin_configure_dt(&control_mode_gpio, GPIO_INPUT)) ||
            (err = gpio_pin_configure_dt(&control_set_gpio, GPIO_INPUT)) ||
            (err = gpio_pin_configure_dt(&control_en_gpio, GPIO_INPUT))) {
        return err;
    }
    if ((err = gpio_pin_interrupt_configure_dt(&control_mode_gpio, GPIO_INT_EDGE_BOTH)) ||
            (err = gpio_pin_interrupt_configure_dt(&control_set_gpio, GPIO_INT_EDGE_BOTH)) ||
            (err = gpio_pin_interrupt_configure_dt(&control_en_gpio, GPIO_INT_EDGE_BOTH))) {
        return err;
    }
    if ((err = gpio_add_callback(port, &control_gpio_callback))) {
        return err;
    }
    return 0;
}

enum control_action control_get_action(void) {
    return atomic_get(&control_action_current);
}

bool control_get_enable(void) {
    return atomic_get(&control_enable_current);
}

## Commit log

2026-01-08 Migrate old hardware to v1 folder.
    [boost.kicad_sch, half-bridge.kicad_sch, inverter.kicad_sch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]
2026-01-08 Partial draft of v2 hardware.
    [pdlc-output.kicad_sch, pdlc.kicad_pcb, pdlc.kicad_sch]
2026-01-15 Finalize for production of v2 revision.
    [pdlc-output.kicad_sch, pdlc.kicad_pcb, pdlc.kicad_sch]
2026-02-19 Implement initial firmware for v2 hardware.
    Noted in errata that the PFM buck converter does not work in this
    application and must be replaced by an FPWM version although there are
    tradeoffs and the output stage is inefficient at low load.
    Generate complementary sine waves for the output using the DAC and DMA.
    Provide basic on-off control and status reporting, no menu system yet.
    [stm32l1_custom.cfg]
